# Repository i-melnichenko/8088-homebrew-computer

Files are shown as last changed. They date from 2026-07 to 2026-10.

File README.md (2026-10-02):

# 8088 Homebrew Computer

An open-source modular computer built around the Intel 8088 CPU.

## Overview

This project explores the design of a modular 8088-based computer using
through-hole DIP components and a custom expansion architecture.

The project is developed incrementally, starting with a minimal working
system and gradually adding new hardware and software capabilities.

## Firmware and host tools

The [ROM BIOS](firmware/8088-mainboard/README.md) builds a 32 KiB EEPROM image
and runs a UART monitor directly from ROM. It initializes an
HD44780-compatible 20×4 LCD on `Exp1` and a GM16C550 UART on `Exp0`, then
loads and runs programs in SRAM. The boot menu can test payload RAM, show board
information and run UART-loaded programs. Default OS boot is not implemented
yet.

Build the BIOS with NASM, then use [boardctl](tools/boardctl/README.md) on the
host to communicate over the UART. `boardctl` requires Go 1.26 or later and
uses macOS `stty` to configure the serial port. From the repository root:

```sh
make -C firmware/8088-mainboard
go -C tools/boardctl run ./cmd -port /dev/cu.usbserial-XXXX info
go -C tools/boardctl run ./cmd -port /dev/cu.usbserial-XXXX keyboard
```

The menu remains on the board LCD; `keyboard` sends Up/Down, Enter and Esc
from the host terminal. Programs receive the same input through polled INT 16h;
revision 1 does not use hardware interrupts. `boardctl` also supports program
upload and management, RAM inspection, and EEPROM readback. EEPROM writing is
not implemented on revision 1. See the [firmware guide](firmware/8088-mainboard/README.md)
for builds and BIOS behavior, and the [boardctl guide](tools/boardctl/README.md)
for commands and examples.

## Mainboard Rev. 1.0

| Front | Back |
| --- | --- |
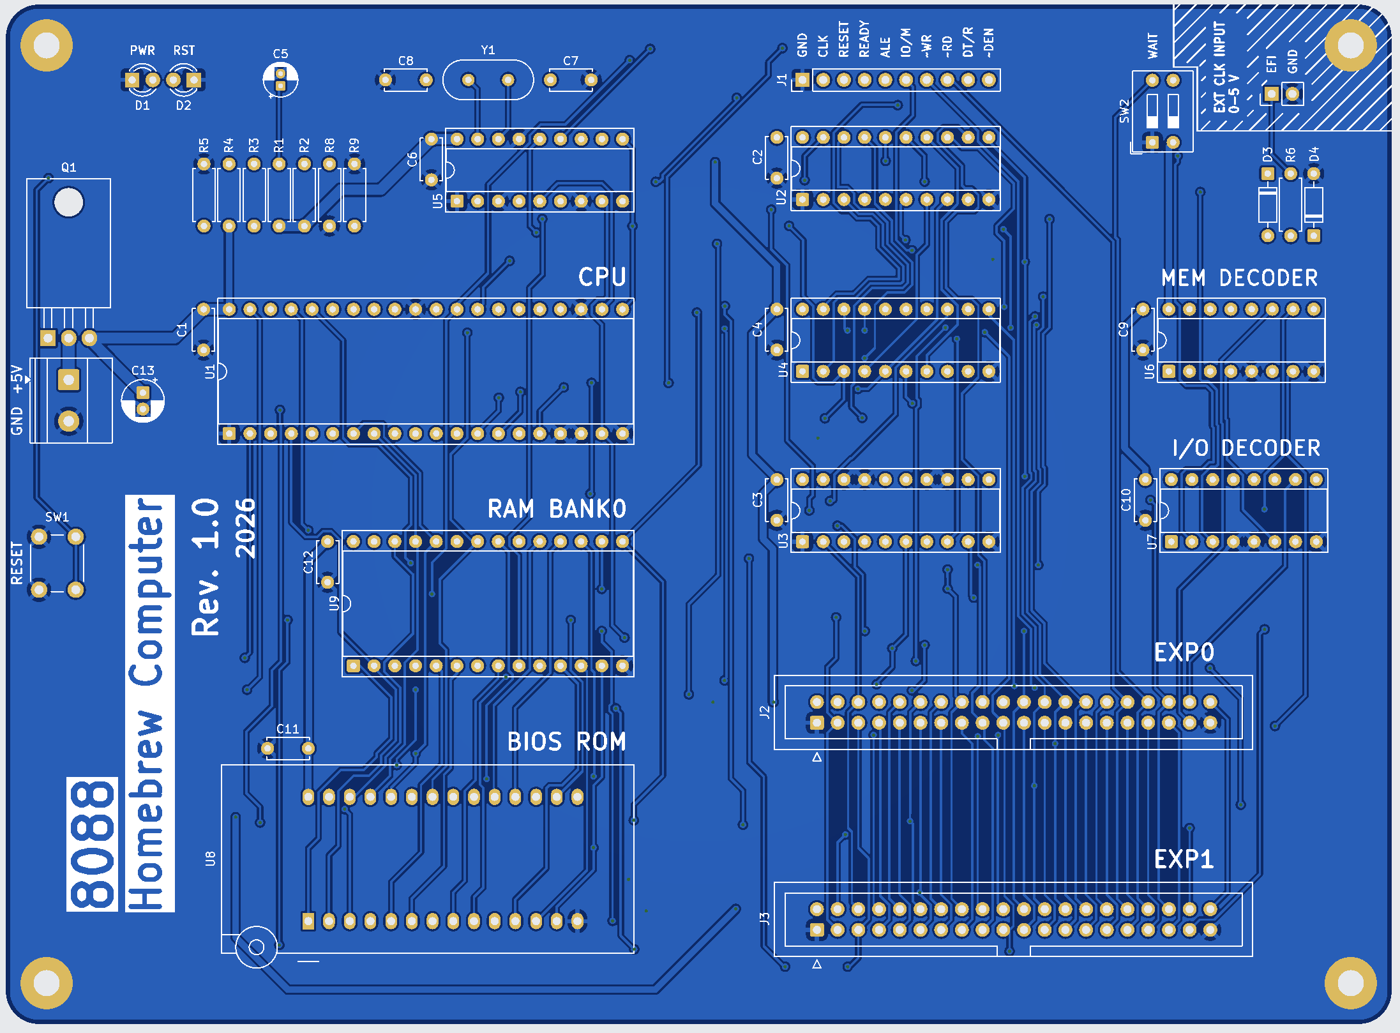
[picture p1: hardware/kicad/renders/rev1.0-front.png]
Front render
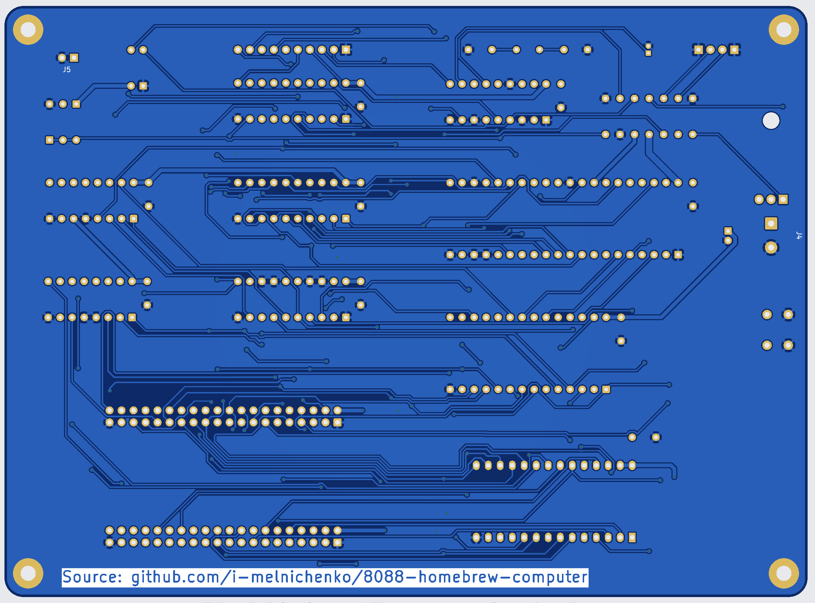
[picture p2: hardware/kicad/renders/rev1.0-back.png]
Back render
|  |  |

### Bill of materials

The table below is derived from [`hardware/kicad`](hardware/kicad). All
components are through-hole.

| Designators | Qty. | Part / value | Footprint / notes |
| --- | ---: | --- | --- |
| U1 | 1 | Intel 8088, minimum mode | DIP-40, 15.24 mm socket footprint |
| U2, U3 | 2 | 74LS373 | DIP-20, 7.62 mm socket footprint |
| U4 | 1 | 74LS245 | DIP-20, 7.62 mm socket footprint |
| U5 | 1 | 8284 clock generator / driver | DIP-18, 7.62 mm socket footprint |
| U6, U7 | 2 | 74LS138 | DIP-16, 7.62 mm socket footprint |
| U8 | 1 | 28C256 EEPROM | DIP-28 socket footprint; 3M 228-1277-00-0602J |
| U9 | 1 | HM62256BLP SRAM | DIP-28, 15.24 mm socket footprint |
| Q1 | 1 | NDP6020P P-channel MOSFET | TO-220-3, horizontal tab-down |
| Y1 | 1 | 14.31818 MHz crystal | HC-49/U, vertical |
| R1, R2, R5, R8, R9 | 5 | 10 kΩ | DIN0207 axial, 7.62 mm pitch |
| R3 | 1 | 680 Ω | DIN0207 axial, 7.62 mm pitch |
| R4 | 1 | 2 kΩ | DIN0207 axial, 7.62 mm pitch |
| R6 | 1 | 1 kΩ | DIN0207 axial, 7.62 mm pitch |
| C1–C4, C6, C9–C12 | 9 | 100 nF ceramic | Disc capacitor, 5.00 mm pitch |
| C5 | 1 | 10 µF electrolytic | Radial, 1.50 mm pitch |
| C13 | 1 | 220 µF electrolytic | Radial, 2.00 mm pitch |
| D1 | 1 | Power LED | 3 mm THT LED |
| D2 | 1 | Reset LED | 3 mm THT LED |
| D3, D4 | 2 | BAT85 Schottky diode | DO-35 / SOD-27, 7.62 mm pitch |
| SW1 | 1 | Reset pushbutton | 6 mm THT tactile switch |
| SW2 | 1 | 2-position DIP switch | SPST ×2, 2.54 mm pitch |
| J1 | 1 | 10-pin connector | 1×10 pin header, 2.54 mm pitch |
| J2, J3 | 2 | Expansion connectors (Exp0, Exp1) | IDC header, 2×20, 2.54 mm pitch |
| J4 | 1 | 5 V power input | 2-pin Phoenix MKDS-1,5, 5.08 mm pitch |
| J5 | 1 | External clock input | 1×2 pin header, 2.54 mm pitch |

> **Rev. 1.0 note:** Do not populate C7 or C8. These capacitors were removed
> from the Rev. 1.1 design.

For ICs, sockets are recommended; the PCB footprints already provide for them.

### Display module

The table below is derived from the
[`display-module` schematic](hardware/kicad/display-module/display-module.kicad_sch).

| Designators | Qty. | Part / value | Footprint / notes |
| --- | ---: |---| --- |
| U1 | 1 | 74LS00 | DIP-14, 7.62 mm socket footprint |
| U2 | 1 | 74LS373 | DIP-20, 7.62 mm socket footprint |
| DS1 | 1 | WC1602A 16×2 LCD in schematic; current build uses a 20×4 LCD | 1×16, 2.54 mm pin socket |
| C2, C3 | 2 | 100 nF ceramic | Disc capacitor, 5.00 mm pitch |
| R2 | 1 | 650 Ω | DIN0207 axial, 7.62 mm pitch |
| RV1 | 1 | 10 kΩ potentiometer | Runtron RM-065, vertical |
| J1 | 1 | Expansion connector (Exp1) | 2×20 pin socket, 2.54 mm pitch |

### UART module

The table below is derived from the
[`uart-module` schematic](hardware/kicad/uart-module/uart-module.kicad_sch).

| Designators | Qty. | Part / value | Footprint / notes |
| --- | ---: | --- |---|
| U1 | 1 | GM16C550 UART | DIP-40, 15.24 mm |
| Y1 | 1 | 1.8432 MHz crystal | HC-49/U, vertical |
| C1 | 1 | 22 pF ceramic | Disc capacitor, 5.00 mm pitch  |
| C2 | 1 | 47 pF ceramic | Disc capacitor, 5.00 mm pitch  |
| C3 | 1 | 100 nF ceramic | Disc capacitor, 5.00 mm pitch  |
| R3–R6 | 4 | 10 kΩ | DIN0207 axial, 7.62 mm pitch |
| R1 | 1 | 1 MΩ | DIN0207 axial, 7.62 mm pitch |
| R2 | 1 | 1.5 kΩ | DIN0207 axial, 7.62 mm pitch |
| R7 | 1 | 1 kΩ | DIN0207 axial, 7.62 mm pitch |
| R8 | 1 | 2 kΩ | DIN0207 axial, 7.62 mm pitch |
| J1 | 1 | Expansion connector (Exp0) | 2×20 pin socket, 2.54 mm pitch |
| J2 | 1 | CP2102 module | 1×03 pin header, 2.54 mm pitch |

## Links

- [DIY EEPROM Programmer](https://github.com/erikvanzijst/eeprom)

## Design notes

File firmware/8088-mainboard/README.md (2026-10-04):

# 8088 mainboard firmware

There is one active ROM BIOS. It initializes both available console devices:
the 20×4 HD44780-compatible LCD on Exp1 and the GM16C550 UART module on Exp0.
The monitor runs directly from ROM at `F800:0000`; uploaded programs execute
from paragraph-aligned SRAM addresses allocated by BIOS.

BIOS sources are grouped by responsibility:

- `bios/uart/`: wire protocol constants, framing, command dispatch and handlers
  for programs, memory, keyboard events, Info and flasher mode.
- `bios/`: initialization, the cooperative monitor loop, shared SRAM state,
  keyboard queue, program allocation, LCD menu and interrupt API.
- `bios/utils/`: self-contained BIOS utilities such as the RAM diagnostic.
- `lib/`: shared hardware drivers and the program BIOS API definitions.
- `programs/flasher/`: the standalone RAM flasher, sharing UART framing and
  protocol constants with BIOS.

## Build

Run these commands from `firmware/8088-mainboard`. NASM is required for
local builds; Go is required for the UART tools.

```sh
make        # build/bios.bin, a complete 32 KiB 28C256 image
make citylights # build/citylights.bin, UART-loaded city animation
make terminal  # build/terminal.bin, UART-to-LCD terminal
make clean
```

BIOS builds print occupied ROM bytes, percentage and free space. The report
includes code/data and the reset vector, excluding `0xFF` padding.

The build supplies the BIOS version: `dev` by default, or an explicit short
identifier for CI/release builds:

```sh
make BIOS_VERSION=v1.0.0
```

Use 1–9 ASCII characters (letters, digits, dots, hyphens or underscores) so
the version remains readable in the LCD header and Info list. The same version
appears in the menu, LCD Info and UART `INFO` reply. BIOS is rebuilt on each
invocation to apply version changes without `make clean`; example programs
still build incrementally. Board revision, UART protocol version and BIOS API
revision are independent. `make test BIOS_VERSION=ci-test` also passes the
version to the Docker build.

## UART and menu control

```sh
make serial-ports
make keyboard SERIAL_PORT=/dev/cu.usbserial-XXXX
make serial SERIAL_PORT=/dev/cu.usbserial-XXXX
```

`make serial` opens the UART console through `boardctl`, without `cu` lock
files or `sudo`; use `Ctrl-C` to leave it. The UART uses `A0h` through `A7h` and is configured for 9600 8N1 from the
module's 1.8432 MHz crystal. The LCD remains on `C0h` (commands) and `C1h`
(data). See the [boardctl guide](../../tools/boardctl/README.md) for CLI commands.

### Boot menu

After boot, the ROM BIOS shows a menu: **Default boot**, **Custom programs**,
**Memory check**, and **Info**. Default boot currently reports `NO BOOT TARGET`;
there is no countdown or DOS loader yet. All menu/monitor code executes from
EEPROM, not copied to RAM. RAM holds only buffers, state, stack and explicit
user uploads; the diagnostic writes RAM only after confirmation.

The first LCD row is the current section header, except for the two-line
Memory check warning dialog. Progress, success, failure and cancellation retain the `MEMORY CHECK`
header; changing status uses rows 2–4. `INFO` is a scrollable list with three
visible rows: BIOS version, board revision, CPU, physical RAM/ROM sizes, LCD,
UART, protocol/API revisions, committed program count and address ranges.
Up/Down scroll one row without wrapping, Enter does nothing, Esc returns to
the selected root item. The rightmost column shows the same `^`/`v` rail as
the menu, without a selection cursor. Reopening Info starts at the top.
The UART `INFO` command still returns its compact ASCII summary.
While launching a payload,
the program name stays on row 1 and `RUNNING PROGRAM` appears on row 2.
The payload then owns the LCD and may use its own layout.

`boardctl keyboard` shares the PC terminal keyboard; the menu is shown only
on the board LCD. Use Up/Down, Enter and Esc to navigate. Ordinary letters,
including `U` and `Q`, belong to the program, not the host utility.
Press `Ctrl-]`, then `u` for a binary path prompt; `Ctrl-C` disconnects directly
and restores the PC terminal, including from the prompt.
Uploads are available only while the ROM menu is active; the new slot is
selected without starting it. Enter opens its details; Enter again starts it.
The submenu always contains four slots, initially Empty.
The last LCD column shows `|` with `^`/`v` for hidden items above/below.
The selected `>` blinks in the root and Custom programs menus, and becomes
visible again on navigation. Only that LCD cell is updated; UART polling
continues without a blocking delay. Revision 1 counts idle-loop iterations,
so the blink rate depends on CPU speed and monitor traffic, not a hardware
timer. Info and other non-selectable pages do not blink.
Use one serial client at a time; do not run a
separate `upload` process while `keyboard` owns the port. Ordinary `upload`
works from any menu page except during an active RAM test.

Revision 1 has no hardware interrupts. The ROM loop polls keyboard packets;
RAM programs must call INT 16h/AH=01h regularly, or wait with AH=00h, to poll
the transport. AH=01h does not consume a key. A program that does not poll
cannot accept keyboard packets; host timeouts and UART overflow are possible.
The BDA holds a 15-key queue shared by the menu and INT 16h. Keyboard sharing
owns UART RX: raw INT 14h/AH=02h is rejected until the host detaches.
`console` remains a separate raw UART mode. Attach keyboard sharing from the
ROM menu before launching a program. Reset disables sharing; reconnect the
host session afterward. If detach cannot be acknowledged, Reset restores raw mode.

## Uploaded programs

For example, build the city animation with `make citylights`, then upload
and start it from this directory:

```sh
go -C ../../tools/boardctl run ./cmd -port /dev/cu.usbserial-XXXX upload \
  --name "City Lights" --run ../../firmware/8088-mainboard/build/citylights.bin
```

Omit `--run` to add the program to the menu without starting it. The animation
shows `CITY LIGHTS` over the skyline for about two seconds, then alternates
between night and day. Stars twinkle between a bright shape and a dim dot at
night; clouds drift left during the day. One pedestrian paces on the left,
while two small buildings remain on the right.
The moon and sun stay in place. Each scene lasts about five seconds before a
right-to-left column wipe reveals the next one. The lower-right `ESC:BACK`
hint appears for about three seconds, hides for
about ten, and repeats; Esc always returns to BIOS. Timing is approximate on
rev1 because it has no hardware timer.

The `terminal` example displays keyboard input on the LCD and echoes it over
UART. Its header and controls stay on the top two rows; Esc returns to BIOS.

The host sends a name, image size and CRC; BIOS assigns an ID and a
paragraph-aligned address. Up to four programs
may coexist. First-fit allocation reuses deleted ranges without relocating
resident programs; allocations remain paragraph-aligned. `PROGRAM_DELETE`
frees a slot/range and shifts following IDs; `PROGRAM_RENAME` changes only its
name. Both operations refresh the LCD and require no active upload/test/program.
The current upload area is `0x8800..0xFBFF` (29,696 bytes total, less alignment gaps).
The first 2 KiB of physical SRAM are reserved for IVT, BDA and BIOS state;
`0xFC00..0xFFFF` is reserved for program and BIOS stacks. The decoder mirrors
the 32-KiB SRAM every 32 KiB within `0x00000..0x1FFFF`.
BIOS maintains the sequential upload cursor; DATA packets contain only program
bytes, 128 per block except the final remainder. Uploads must be
fully received with matching image CRC before a slot becomes runnable. Retried PROGRAM_UPLOAD_DATA packets
are acknowledged without counting their data twice. The LCD shows transfer
progress as a 20-character `[###    ]`-style bar with 18 cells between the
brackets. See [protocol v1](../../docs/uart-protocol-v1.md) for the wire format and
commands. Protocol version remains 1 during development; update BIOS and
boardctl together.

`MEMORY_READ` lets boardctl dump RAM (including BIOS state and mirrors)
in blocks of up to 127 bytes. It is available in the ROM menu, not during a
memory check or program execution. ROM, unmapped and out-of-range reads are rejected;
live BIOS state is not an atomic snapshot. See the boardctl
[dump examples](../../tools/boardctl/README.md#commands).

`MEMORY_WRITE` permits raw writes only to payload SRAM and its aliases, never
ROM, IVT/BDA, BIOS state or stacks. Writes are rejected while an upload, memory
check or program is active. It does not register programs; boardctl `write`
verifies written bytes by SHA-256 readback.

Normal RETF preserves uploaded programs; Reset, power-off or jumping to
`F800:0000` clears the registry. There is no memory isolation between programs
and BIOS.

## BIOS flasher mode

`BIOS_FLASHER_MODE()` copies the built-in EEPROM monitor to RAM and
transfers control to it. The command has no payload; the full EEPROM
image size is fixed at 32 KiB. Entry works on revision 1 and clears the
resident program registry and keyboard sharing because the monitor occupies
payload RAM. Entry during a program upload, memory test or running program
is rejected. The RAM monitor's ACK confirms it is ready.

Only `BIOS_WRITE`, `BIOS_READ`, `RESET` and `PING` work in this mode; other
requests return status 20. An identical entry retry repeats its ACK. On
revision 1, a valid WRITE returns status 17 (unsupported), READ reads EEPROM in blocks
of 1–127 bytes, and RESET returns to the unchanged ROM BIOS. In the ordinary
ROM menu, READ and WRITE return status 17; enter EEPROM mode to read.
Both commands carry physical addresses and validate the entire block within
`0xF8000..0xFFFFF` in the RAM flasher; invalid requests return status 18.
The UART configuration/FIFO are preserved during
entry; hardware interrupts stay disabled and all monitor code runs from RAM.

The LCD switches to a `BIOS FLASHER` status screen in the same four-row style
as BIOS: section header, operation result, EEPROM address range and
`HOST RESET TO EXIT`. Entry shows `READY - READ ONLY`; successful reads show
`READ OK` and the inclusive physical range of the block. Revision-1 writes
show `WRITE UNSUPPORTED`, while invalid requests display an error. PING and
identical entry retries preserve the latest operation result. LCD updates
run one short operation per UART polling iteration, entirely from RAM.
RESET returns to the BIOS menu; keyboard navigation is disabled in this mode.

The revision-2 contract uses the same mode and commands, adding EEPROM writes
in WRITE; the write driver is not implemented yet. Blocks are written and
verified immediately. The host can read the
complete image with READ and compare SHA-256 before RESET; after a write,
RESET requires all 32 KiB to have been written and verified by readback.
See the [wire contract](../../docs/uart-protocol-v1.md#bios-flasher-mode).
The flasher lives in [`programs/flasher/main.asm`](programs/flasher/main.asm);
EEPROM hardware drivers belong in `lib/`. The flasher is assembled separately
with `ORG 0` so it can execute from RAM without calling ROM services.
`make bios` builds the normal 32-KiB EEPROM image containing the RAM monitor;
it does not build a second BIOS image. boardctl exposes `bios-flasher-mode`, `bios-read`
and `bios-write`; see its [EEPROM guide](../../tools/boardctl/README.md#bios-flasher-mode).

## Memory check

Memory check asks for confirmation because it destroys all uploaded programs.
The dialog shows `ALL RAM PROGRAMS` and `WILL BE DELETED!` on rows 1–2,
a blank row 3 and `YES:ENTER  NO:ESC` on row 4. Enter starts the destructive
test; Esc returns to the menu without changing programs or their RAM contents.
It tests the complete 32-KiB SRAM through its `0x8000..0xFFFF` alias. The
program area (`0x8800..0xFBFF`) uses destructive write/read passes; the IVT,
BDA, monitor/API state and stacks are checked one byte at a time and restored
after each probe. The five test values are `00`, `FF`, `55`, `AA`, and
address-dependent data. Row 2 shows overall progress across
all ten passes with the same bracketed 18-cell bar; row 3 shows the current
inclusive 16-byte RAM range,
and row 4 shows six-digit decimal `OK`/`BAD` counters. These count byte
verifications, not unique addresses: each of 32,768 bytes is checked five
times, so a successful full test reports `OK:163840 BAD:000000`. Writes do
not increment these counters. Testing continues after mismatches and retains
the first failing address, expected and actual byte in BIOS state. After
completion row 3 shows `DONE FFF0-FFFF`, or `FAIL xxxx-yyyy` for the block
containing the first mismatch. After cancellation it shows `STOP xxxx-yyyy`
for the last processed block. Completion keeps a full bar and the
totals, while cancellation keeps partial progress and counters.
Esc cancels. Cancellation also invalidates
all old programs. This is a basic diagnostic, not an exhaustive
RAM certification test. UART requests remain serviceable throughout the test.

## Program BIOS API

Programs call real software interrupts: INT 10h for text/cursor/scrolling,
INT 14h for UART, INT 16h for UART-backed keyboard, and INT 60h for board
LCD services, including custom CGRAM glyphs. Include `lib/bios_api.inc`;
the examples no longer include their own copies of the hardware drivers.
Programs use `ORG 0`, start with `DS=CS`, preserve `SS/SP`, and use `RETF`
to return to the menu. Handlers live in ROM and return with IRET, preserving caller segments,
stack and non-output registers/flags. Revision 1 needs no PIC for software INT.
See [bios-api.md](docs/bios-api.md) for exact registers, flags, supported
functions, memory aliases and limitations. This is not a full PC/MS-DOS BIOS.

## Software verification

The Docker tests execute the actual ROM image with Unicorn and emulated
UART/LCD. They cover keyboard navigation, LCD output, upload retries and bounds,
RAM pass/fail/cancel, program return, SRAM mirrors and INT API contracts.
The emulator implements CPU IVT dispatch; real ROM handlers and IRET execute.
It does not verify hardware timing.

Run the emulator checks in Docker (Docker must be running):

```sh
make test
```

The image installs NASM/Make and the pinned Unicorn dependency, rebuilds the
ROM inside Linux, then runs the tests. It does not access the EEPROM, serial
devices, or write host build files. This is a test runner, not an interactive
virtual board. `EMULATOR_IMAGE` overrides the local Docker image name.

## Current scope

There is no automatic boot countdown, bootable storage or MS-DOS loader yet.
Revision 1 polls UART and does not use hardware interrupts. The implemented
software INT services are a starting point, not a complete PC-compatible BIOS.
Revision 2 can extend these services, add hardware interrupt support, memory
discovery and storage boot while keeping one BIOS implementation.

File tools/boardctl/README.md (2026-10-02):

# boardctl

`boardctl` is the host-side command-line tool for the 8088 mainboard monitor
protocol. It communicates over the GM16C550 UART at 9600 8N1 and loads flat
16-bit binaries into SRAM.

The wire format is documented in [uart-protocol-v1.md](../../docs/uart-protocol-v1.md).

## Build

Go 1.26 or later is required.

```sh
go build -o boardctl ./cmd
```

The tool uses the macOS built-in `stty` command to configure the serial device.

## Monitor status

The monitor executes directly from ROM at `F800:0000`. It implements `keyboard`, `info`,
`upload`, `programs`, `run`, `delete`, `rename`, `dump`, `write`, `ping`, and `reset`;
uploaded programs execute from SRAM.
`bios-flasher-mode`, `bios-read` and `bios-write` use the built-in RAM flasher.

The `console` command is usable now. The default device is
`/dev/cu.usbserial-110`; use `-port` to select another one.

```sh
./boardctl -port /dev/cu.usbserial-XXXX info
```

## Commands

```sh
# Open a plain UART console. Ctrl-C exits.
./boardctl -port /dev/cu.usbserial-XXXX console

# Share the PC keyboard; menu and program output stay on the board LCD.
./boardctl -port /dev/cu.usbserial-XXXX keyboard

# Print BIOS/board revision, memory map and UART settings.
./boardctl -port /dev/cu.usbserial-XXXX info

# Check the connection in either the ROM menu or RAM flasher.
./boardctl -port /dev/cu.usbserial-XXXX ping

# Name a program, let BIOS allocate RAM, and immediately execute it.
./boardctl -port /dev/cu.usbserial-XXXX upload \
  --name "City Lights" --run ../../firmware/8088-mainboard/build/citylights.bin

# List resident program IDs, names, addresses and sizes.
./boardctl -port /dev/cu.usbserial-XXXX programs

# Execute a binary that was previously uploaded.
./boardctl -port /dev/cu.usbserial-XXXX run 1

# Rename a resident without reloading it, or delete it and free its RAM.
./boardctl -port /dev/cu.usbserial-XXXX rename 1 Penguins
./boardctl -port /dev/cu.usbserial-XXXX delete 1

# Return execution to ROM reset handling.
./boardctl -port /dev/cu.usbserial-XXXX reset

# Print 256 bytes of RAM as an address/hex/ASCII dump.
./boardctl -port /dev/cu.usbserial-XXXX dump --addr 0x8800 --size 256

# Save the 32-KiB RAM bank to a new binary file.
./boardctl -port /dev/cu.usbserial-XXXX dump \
  --addr 0 --size 32768 --output ram-dump.bin

# Write raw bytes into payload RAM, then verify SHA-256 by readback.
./boardctl -port /dev/cu.usbserial-XXXX write --addr 0x9000 patch.bin

# Enter the RAM flasher and save the complete EEPROM image (works on Rev.1).
./boardctl -port /dev/cu.usbserial-XXXX bios-read --output bios-dump.bin

# Read EEPROM and compare its SHA-256 with a local 32-KiB BIOS image.
./boardctl -port /dev/cu.usbserial-XXXX bios-read \
  --verify ../../firmware/8088-mainboard/build/bios.bin

# Flash on writing hardware, verify SHA-256, then reset to the new BIOS.
./boardctl -port /dev/cu.usbserial-XXXX bios-write --reset \
  ../../firmware/8088-mainboard/build/bios.bin
```

`upload` sends name, size and image CRC in `PROGRAM_UPLOAD_BEGIN`, receives an ID and
address, sends `PROGRAM_UPLOAD_DATA` payloads containing only program bytes
(128 per block, except the final remainder). Before `PROGRAM_UPLOAD_COMMIT`,
boardctl reads the entire assigned range back through `MEMORY_READ` and compares
its SHA-256 with the original binary on the PC. Only a matching hash permits
COMMIT with the one-byte program ID. Read failures or mismatched hashes trigger
ABORT where possible; the program is not committed or run. Hash mismatches
report both PC and RAM hashes. This check also applies to uploads from keyboard
sharing. Readback adds roughly another transfer's worth of UART time.
BIOS still independently verifies the image CRC16 during COMMIT.
BIOS advances its own write cursor; boardctl
waits for each ACK and retries the same sequence on timeout.
The LCD displays `RECEIVING...` and a 20-cell progress bar during the
transfer. The current SRAM upload range is `0x8800` through `0xFBFF`
(29,696 bytes); the upper 1 KiB is reserved for the stack.
Up to four named programs may coexist. BIOS assigns paragraph-aligned addresses
starting at `0x8800`; `--addr` is no longer supported. Programs use `ORG 0`,
DS=CS, preserve SS/SP and return with RETF. Old ORG-0200 binaries must be rebuilt.
The INT API reserves IVT/BDA and state below 8800h; update boardctl and BIOS
together. Programs may use the [BIOS API](../../firmware/8088-mainboard/docs/bios-api.md) rather than
including hardware drivers. Both examples have been migrated.
Name defaults to the file stem; `--name` overrides it. Names must be unique,
1–15 printable ASCII characters and not all spaces. Failed uploads are aborted
where possible; already committed programs remain available.

`rename ID NAME` preserves the program's address, size and bytes; the new name
follows the same 1–15 ASCII and uniqueness rules as upload. `delete ID` frees
the slot and allocation but does not erase RAM or relocate other programs.
BIOS uses first-fit allocation to reuse deleted ranges. Following program IDs
shift after deletion: run `programs` again before using saved IDs. Both commands
require the ROM menu and no pending upload or memory check. Deleting switches
the LCD to Custom programs. Retries cannot delete the next ID a second time.

`dump` uses `MEMORY_READ` in chunks of at most 127 bytes. Both `--addr` and
`--size` are required; decimal and `0x`-prefixed hex are supported. The range
must lie entirely in RAM `0x00000..0x1FFFF` (four mirrors of 32 KiB).
ROM reads are rejected. Protected BIOS RAM is readable, but live state and buffers
are not atomic snapshots. Use the ROM menu: memory checks reject reads, and
running programs cannot be dumped. With `--output`, the file is created only
after a successful full read; existing files are never overwritten.

`write --addr ADDRESS FILE` uses `MEMORY_WRITE` in chunks of at most 124 bytes.
Both boardctl and BIOS check the entire range: only payload RAM `0x8800..0xFBFF`
and its aliases (`0x00800..0x07BFF`, `0x10800..0x17BFF`, `0x18800..0x1FBFF`) are
writable. ROM, unmapped memory, IVT/BDA, BIOS state and stacks are protected.
After writing, boardctl reads the entire range back and checks SHA-256. Writes
are rejected during uploads, memory checks and program execution. Raw writes
do not create a menu slot: use `upload` for programs. Existing program bytes
can be overwritten, and a failed multi-block write may leave a partial patch;
there is no rollback.

## BIOS flasher mode

`bios-flasher-mode` sends `BIOS_FLASHER_MODE` with an empty payload. Entry copies
the BIOS's embedded flasher to RAM and clears resident programs and keyboard
sharing. The EEPROM
image is always 32,768 bytes. This command works on Rev.1. In EEPROM mode only
`BIOS_WRITE`, `BIOS_READ`, `PING` and `RESET` are available, plus an identical
lost-ACK entry retry. Use `ping` to check the connection and `reset` to return
to the ROM BIOS when firmware permits it.

`bios-read [--output FILE] [--verify FILE]` reads all 32 KiB using `BIOS_READ`
blocks of up to 127 bytes and prints the EEPROM SHA-256. Requests carry physical
addresses in `0xF8000..0xFFFFF`; the host and flasher validate the entire range.
RAM, EEPROM mirrors and addresses outside this window are rejected. It probes the mode:
from the ROM menu it enters the RAM flasher automatically;
if already in the flasher it reads without reentering. `--verify` compares
SHA-256 with an exact 32-KiB file, including padding
and reset vector. `--output` saves a new binary file only after all reads and
any requested verification succeed; existing files are never overwritten.
The command leaves the board in EEPROM mode and does not reset it.

`bios-write [--reset] [--timeout DURATION] FILE` requires an exact 32-KiB image
and a board in its ordinary ROM menu. It probes the mode before entering the RAM
flasher, then sends consecutive 64-byte EEPROM pages through
`BIOS_WRITE`. Each request is acknowledged before the next page; retries keep
the same sequence, physical address and bytes, including across sequence wrap. The RAM
flasher performs per-block write/readback checks. boardctl then reads
the entire EEPROM through `BIOS_READ` and compares SHA-256 with the source.
`--reset` sends RESET only after that verification succeeds; otherwise the
board remains in the RAM flasher. Any write/readback error stops the transfer
without sending RESET. The per-WRITE-attempt timeout defaults to 10 seconds
and can be increased, for example `--timeout 30s`, for EEPROM programming and
readback verification.

Rev.1 supports entry and readback; a valid WRITE returns status 17
(`unsupported operation`) without writing. Invalid requests in the RAM flasher
return status 18. The Rev.2 EEPROM write driver is not implemented in the
current firmware; the host flash command implements its
protocol contract. An already active EEPROM session is rejected for a new
flash. After a SHA-256 mismatch, do not reset into the unverified BIOS.
The protocol permits a new full transfer from the active flasher after
completion, starting with WRITE at `0xF8000`; the current CLI does not expose
that recovery operation. The host does not reset or restart a write automatically.

## Keyboard sharing

Run from this directory without building a binary:

```sh
go run ./cmd -port /dev/cu.usbserial-0001 keyboard
```

The entry point is `cmd/main.go`; application logic lives in `internal/apps`.
`internal/client` handles monitor requests, response matching, and retries;
`internal/protocol` encodes and decodes wire frames.
`keyboard` translates terminal input into ASCII/PC-style scan-code events.
It does not fetch, redraw or mirror the BIOS menu on the PC.
It restores the terminal settings on normal exit and handled signals.

Connect while the board is in its ROM menu, then use Up/Down, Enter and Esc
to navigate on the LCD. Wait for `Keyboard connected` before typing: while
attaching, the terminal is still in its normal mode. Ctrl-C cancels attachment
as well as an active session, including while a key acknowledgement is pending.
Failed/interrupted attachment also attempts to detach, since BIOS may have
accepted the request before its acknowledgement was received. A malformed
keyboard acknowledgement reports its actual payload bytes and length.
Programs read the same input through INT 16h.
UART reads are nonblocking and return periodically even without incoming
bytes; write waits are bounded. This lets retry deadlines and Ctrl-C run on
macOS instead of getting stuck inside Go's file readiness wait. The serial
descriptor stays open while `stty` configures it, so closing the configuration
command does not reset settings before the UART exchange.
Letters, including `U` and `Q`, and Ctrl-Z are forwarded to the program.
Arrows, Home/End, Insert/Delete, Page Up/Down and F1..F10 are translated;
modifier state, key releases and Unicode text are not supported.

Press `Ctrl-]`, then `u` to open a path prompt. Paste/type a binary path, press Enter to upload to
an address assigned by BIOS. Its file stem becomes the program name. After
upload the new Custom programs slot is selected: Enter opens details, then
Enter runs it. Paths may contain
spaces; shell quote characters and `~` are not expanded. Esc cancels the prompt.
Uploads are allowed only after returning to the BIOS menu. `Ctrl-C` detaches
and quits directly, including from the upload prompt. It is intercepted in
raw mode and not forwarded to BIOS. Terminal
settings are restored on exit. `Ctrl-]`, then `q` remains an exit alias;
`Ctrl-]`, then `]` forwards a literal Ctrl-].

Revision 1 has **no hardware interrupts**. In RAM programs, INT 16h/AH=00h
waits while polling input; AH=01h polls and peeks without consuming a key.
Programs doing other work must call AH=01h regularly. A program that does not
poll cannot acknowledge keyboard events; long delays can overflow the UART
FIFO. The BIOS ring holds up to 15 keys after packets have been received.
The host reports failed acknowledgements/queue errors; it does not promise
unlimited buffering or asynchronous input. Raw INT 14h receive is unavailable
while sharing owns RX. UART TX/status still work, but this mode does not
display program UART output. Use `console` separately for raw UART programs.

Sharing survives ordinary RETF. Reset disables sharing, so restart the host
session after Reset. If a non-polling program prevents detach, Reset restores
raw UART mode. Do not attach sharing to an already-running raw-input program.

Only one process may own the serial port. Use the built-in upload action while
sharing, or close the session before using the separate `upload` command.
Custom programs has four slots, initially Empty. The rightmost LCD column
shows `^`/`v` when more items exist above/below. Reset and confirmed memory
check clear the registry; ordinary program return preserves it.
Menu memory check erases the payload only after confirmation; an active test
rejects uploads and can be cancelled with Esc. Info is a scrollable LCD list:
Up/Down scroll, Esc returns, Enter has no action. The host `info` command
continues to print a compact summary rather than the LCD list. Default boot is a placeholder;
there is no automatic countdown, persistent program selection, or DOS boot yet.

## Current scope

Protocol v1 implements `PING`, `INFO`, `RESET`, `BIOS_FLASHER_MODE`, `BIOS_WRITE`,
`BIOS_READ`, `MEMORY_READ`, `MEMORY_WRITE`; `PROGRAM_UPLOAD_BEGIN`, `PROGRAM_UPLOAD_DATA`,
`PROGRAM_UPLOAD_COMMIT`, `PROGRAM_UPLOAD_ABORT`; `PROGRAM_LIST`, `PROGRAM_EXEC`,
`PROGRAM_DELETE`, `PROGRAM_RENAME`; and
`KEYBOARD_MODE`, `KEYBOARD_EVENT`. Version stays 1 during development; update BIOS and boardctl
together. Each packet uses COBS framing, CRC-16/CCITT-FALSE, sequence numbers,
and host retries. Firmware status 17–20 is reported with a description.
Execution debugging is not implemented.

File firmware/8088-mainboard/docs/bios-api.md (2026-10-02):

# ROM BIOS software-interrupt API

API revision **1** runs on the revision-1 8088 board using real software
interrupts. It is independent of the UART wire protocol version (also 1).
This is a documented subset of PC-style BIOS services plus board extensions,
not a complete IBM PC BIOS or a claim that stock MS-DOS can boot.

## Memory and execution

The current decoder selects RAM for physical 00000h..1FFFFh. Its 32-KiB
SRAM uses A0..A14 only: addresses separated by 8000h refer to the same bytes.
They are aliases, not additional memory. BIOS keeps its existing upper-alias
execution convention, reserving the corresponding low-memory structures:

| Canonical SRAM bytes | Upper alias | Purpose |
| --- | --- | --- |
| 0000..03FF | 8000..83FF | 256 interrupt vectors, offset:segment |
| 0400..04FF | 8400..84FF | BIOS Data Area, partial implementation |
| 0500..06FF | 8500..86FF | monitor buffers, screen, registry |
| 0700..07FF | 8700..87FF | API LCD framebuffer, cursor, keyboard and EEPROM mode parameters |
| 0800..7BFF | 8800..FBFF | program allocations, 29,696 bytes minus alignment gaps |
| 7C00..7DFF | FC00..FDFF | program stack |
| 7E00..7FFF | FE00..FFFF | BIOS stack |

The vectors for 10h, 14h, 16h and 60h point into ROM F800:xxxx. Other vectors
currently lead to the unsupported-service handler. This is not exception
recovery: keep hardware interrupts disabled on revision 1. Software INT
works with IF=0 and does not require a PIC.

Programs remain flat 8086-compatible ORG-0 images. BIOS far-calls their
allocated segment at offset 0, with DS=CS, IF=0 and DF=0. It sets SP=FDFE
before CALL; the program sees SP=FDFA because the far return address uses
four bytes. Preserve SS/SP and use RETF to return to the menu.

Each INT uses the caller's stack and returns with IRET. Unless specified
below, AX/BX/CX/DX/SI/DI/BP/DS/ES and the caller's flags are preserved.
Handlers clear DF internally, then restore the caller's DF/IF through IRET.
Invalid function numbers/parameters return CF=1 and AH=86h; this error
convention is a board extension, not a claim about unspecified PC BIOS cases.
Never access service internals or depend on handler addresses.

The BDA currently initializes COM1 base (0040:0000 = A0h), physical memory
size (0040:0013 = 32 KiB), keyboard ring head/tail (001A/001C) and buffer
(001E..003D, 16 word slots with at most 15 queued keys), display mode
(0049 = custom 7Fh), columns (004A = 20),
framebuffer byte count (004C = 80), page-0 cursor (0050), and last row
(0084 = 3). Other fields are reserved, not implemented PC services.
There is no PC video memory at B800:0000 and no attribute framebuffer.

## INT 10h — LCD text console

Only page BH=0 is supported, except AH=06h where BH is the ignored attribute.
Coordinates are zero-based, row 0..3 and column 0..19.

| AH | Inputs | Operation / outputs |
| --- | --- | --- |
| 02h | BH=0, DH=row, DL=column | Set logical cursor and LCD DDRAM position |
| 03h | BH=0 | Return DX=row:column, CX=2000h (hidden cursor) |
| 06h | AL=lines, BH=attribute, CH/CL=top/left, DH/DL=bottom/right | Scroll the inclusive rectangle upward; AL=0 or AL>=height clears it |
| 0Eh | BH=0, AL=character | Write character, advance cursor and scroll when necessary |

Attributes/colors are ignored on this monochrome character LCD. Teletype
interprets CR (column zero), LF (next row, retaining column), BS (move left,
without erasing or crossing the row boundary), and BEL (no speaker, no-op).
Writing the final column wraps; reaching past row 3 scrolls the whole screen.
Valid video calls preserve FLAGS. This 20x4 custom mode is not PC mode 3.

## INT 14h — serial port

DX is the BIOS port index, **0** for the sole UART, not the A0h I/O address.

| AH | Inputs | Outputs / operation |
| --- | --- | --- |
| 00h | DX=0, AL=E3h | Initialize 9600 8N1, reset FIFOs and keyboard queue; return status as AH=03h |
| 01h | DX=0, AL=byte | Transmit; AL retained, AH=line status or timeout |
| 02h | DX=0 | Receive; AL=byte on success, AH=line status or timeout |
| 03h | DX=0 | AH=line status, AL=modem status |

Initialization configurations other than E3h are not supported yet.
Transmit and receive poll at most 65,535 iterations. On timeout AH bit 7 is
set; do not use the receive AL then. The timeout is CPU-speed dependent,
not a millisecond clock. AH bits 0..6 come from the UART LSR; bit 7 is the
BIOS timeout indicator, not the 16550 FIFO-error-summary bit. Flags and
registers other than AX are preserved on valid calls. No UART IRQ is enabled.
While host keyboard sharing is enabled, AH=02h returns CF=1/AH=86h because
framed keyboard traffic owns UART RX. TX/status remain available; initialization
resets the FIFO and keyboard queue but does not disable sharing. UART text
output is not displayed by the host keyboard command.

## INT 16h — polled keyboard

| AH | Outputs / operation |
| --- | --- |
| 00h | Wait for a key and consume it; AL=ASCII, AH=scan code |
| 01h | ZF=1 when empty (AX unchanged); otherwise ZF=0, AX=key, without consuming |
| 02h | AL=0 modifier state; no physical keyboard modifier tracking yet |

ASCII letters, digits, basic punctuation, Esc, Tab, Backspace and CR have
PC-style scan codes. Uppercase letters use the same scan code as lowercase.
Other raw received bytes have scan code zero. In raw mode CR and LF are
distinct bytes; terminal arrow sequences are not decoded by BIOS.
Only AH=01h changes ZF; other FLAGS are retained.

`boardctl keyboard` enables framed keyboard sharing before program launch.
The host translates terminal arrows, Home/End, Insert/Delete, Page Up/Down
and F1..F10 into keys with AL=0 and a PC-style scan code in AH. Enter becomes
0D/1C, Backspace 08/0E and Esc 1B/01. No modifier/release events or PS/2
decoding are implemented. The BIOS menu consumes the same BDA queue as programs.

There are **no hardware interrupts on revision 1**. Both AH=00h and AH=01h
pump the UART frame decoder, at most one complete request per call. AH=00h
continues polling until a key is available; AH=01h is suitable for cooperative
program loops. Long work without these calls may cause UART overflow or host
timeouts. The 15-key ring cannot prevent hardware FIFO overflow before polling.
Software INT does not make input asynchronous.

For a program doing other work, poll between bounded work slices:

~~~asm
.loop:
    bios_key_peek                 ; INT 16h/AH=01h: pump UART, leave key queued
    jz .work
    bios_key_read                 ; INT 16h/AH=00h: consume, AX=scan:ASCII
    ; Handle AX here.
.work:
    ; Do a short slice of work; do not HLT waiting for a nonexistent IRQ.
    jmp .loop
~~~

In sharing mode, the program-side poll accepts keyboard mode/events and PING;
BIOS_WRITE receives status 17 (unsupported) on revision 1; other valid monitor
commands, including BIOS_FLASHER_MODE and BIOS_READ, receive status 11 (program
busy). Uploads remain
available only in the ROM menu. Sharing survives RETF, but Reset disables it.
Attach from the menu, not while an existing raw-UART program is running.
Raw UART and keyboard input share one port: in sharing mode INT 14h receive
is rejected; in raw mode it cannot consume keys already queued by INT 16h.
Do not mix the two raw input paths while a key is pending.

## INT 60h — board LCD extensions

These are board-specific functions, not replacements for DOS INT 21h.
Success clears CF; failure sets CF and AH=86h. Other flags are retained.

| AH | Inputs | Outputs / operation |
| --- | --- | --- |
| 00h | none | AX=1 revision, BX=B105h signature, CH=4 rows, CL=20 columns, DX=001Fh capabilities |
| 01h | none | Clear LCD/framebuffer and reset cursor; retain pending keyboard input |
| 02h | DH=row, DS:SI=ASCIZ | Replace one line, truncate/pad to 20 cells; cursor retained |
| 03h | AL=glyph 0..7, DS:SI=8 bytes | Load 5x8 CGRAM glyph; only low five bits of each byte used |
| 04h | DH=row, DL=column, AL=raw byte | Write one cell without interpreting controls, advancing cursor or scrolling |
| 05h | DS:SI=ASCIZ | Print string using console teletype rules |

Capabilities bits: 0 text console, 1 UART, 2 keyboard, 3 LCD extensions,
4 host keyboard sharing (cooperative polling, not an IRQ-driven keyboard).
Line/string/glyph functions preserve DS, SI and all other non-output
registers. Strings and glyph buffers belong to the caller; these calls
perform no memory isolation or bounds validation against the program image.
ASCIZ printing requires a valid terminator. After CGRAM operations BIOS
restores the LCD's DDRAM cursor.

## SDK and example

Include firmware/8088-mainboard/lib/bios_api.inc when assembling with
NASM -I lib/. It contains constants and lightweight INT macros, no LCD/UART
drivers. A macro may set argument registers before the INT; register
preservation applies to the interrupt itself, not those setup instructions.

For example:

~~~asm
BITS 16
CPU 8086
ORG 0
%include "bios_api.inc"

    bios_lcd_clear
    bios_print message
    bios_key_read
    retf

message: db 'Hello from INT!', 0
~~~

Both bundled examples use this API. The city animation loads CGRAM glyphs
through INT 60h; the UART terminal reads keys through INT 16h, echoes through
INT 14h and writes LCD cells through INT 60h.
The animation also polls INT 16h between short delay slices; Esc ends its loop.

## Verification and compatibility direction

`make test` from `firmware/8088-mainboard` runs only inside Docker. The emulator maps all four SRAM aliases
to one backing store and emulates CPU INT vector dispatch; the actual ROM
handler and IRET instructions execute in Unicorn. Tests cover vectors/BDA,
upload and memory-test isolation, caller segments/registers/flags/stack,
cursor/scrolling/CGRAM, UART status/timeout, keyboard peek/get and return.
They do not certify the board's wiring or hardware timings.

Future PC compatibility must extend the documented standard services,
memory/BDA organization, disk boot and timer/IRQ handling. This API provides
reusable implementations; it does not emulate an 80x25 display, DOS kernel
calls, PC keyboard hardware or direct PC I/O/video-memory accesses.
Standard reference: [Ralf Brown's Interrupt List](https://www.cs.cmu.edu/~ralf/files.html).

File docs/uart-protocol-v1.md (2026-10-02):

# 8088 board protocol v1

Protocol v1 defines the binary UART interface: framing, command codes,
payloads, replies and retry rules. Supported operations and valid physical
memory ranges are properties of the implementation.

UART uses 8N1; host and board must use the same configured baud rate.
boardctl uses 9600 baud. The baud rate is configured outside the protocol.
This binary protocol is separate from raw console mode. Version remains 1
during unreleased development;
update BIOS and clients together when changing this contract.

## Framing

Every packet is COBS-encoded and delimited by zero bytes:

```text
00 | COBS(decoded-frame) | 00
```

The decoded frame uses little-endian integers:

```text
version:u8 | command:u8 | sequence:u8 | length:u16 | payload | crc16:u16
```

Version is `0x01`; `length` counts payload bytes, at most 128. The common header
is five bytes; a decoded frame occupies `7 + length` bytes including CRC.
The maximum decoded size is 135 bytes, the maximum COBS body is 136 bytes,
and the maximum packet including both delimiters is 138 bytes. Consecutive
zero delimiters are allowed and do not represent empty requests.
CRC-16/CCITT-FALSE uses polynomial `0x1021`, initial `0xFFFF`, no bit reflection
and no final XOR. It covers the decoded header and payload, excluding the CRC,
COBS encoding and delimiters. The CRC is transmitted little-endian;
the check value for ASCII `123456789` is `0x29B1`.

Invalid COBS, CRC, version, declared length or payloads above 128 bytes are
ignored without a reply. An oversized packet is discarded through the next
zero delimiter. A valid frame with an invalid command payload receives that
command's error status instead.

Hosts keep one request in flight. Each new request normally increments
sequence modulo 256; retries retain the command, sequence and all payload
bytes. The board echoes sequence but does not require consecutive values or
provide a global duplicate-request cache. Retry behavior is command-specific.
Clients match both reply command and sequence and ignore unrelated frames
and interleaved console text. boardctl uses one second per response and up to
ten attempts for ordinary requests; BIOS_WRITE defaults to ten seconds per
attempt, configurable with `--timeout`. A nonzero status ends a transaction;
it is not a transport timeout and is not automatically retried by boardctl.

### Complete packet examples

All byte sequences in this section and other byte dumps are hexadecimal;
each two-digit group is one byte. CRC values are shown as integers, then
appended little-endian before COBS encoding. The wire packet includes both
zero delimiters.

PING with sequence `0x2A`, followed by its successful reply:

```text
Request header + payload: 01 01 2A 00 00
CRC16:                    0x8CEE
Decoded frame:            01 01 2A 00 00 EE 8C
COBS body:                04 01 01 2A 01 03 EE 8C
Wire packet:              00 04 01 01 2A 01 03 EE 8C 00

Reply header + payload:   01 81 2A 01 00 00
CRC16:                    0xABE4
Decoded frame:            01 81 2A 01 00 00 E4 AB
COBS body:                05 01 81 2A 01 01 03 E4 AB
Wire packet:              00 05 01 81 2A 01 01 03 E4 AB 00
```

MEMORY_READ with sequence `0x2B`, address `0x8800` and size 2. This example
assumes the target permits that RAM range and it contains bytes `AA 00`:

```text
Request header + payload: 01 07 2B 06 00 00 88 00 00 02 00
CRC16:                    0x75AF
Decoded frame:            01 07 2B 06 00 00 88 00 00 02 00 AF 75
COBS body:                05 01 07 2B 06 01 02 88 01 02 02 03 AF 75
Wire packet:              00 05 01 07 2B 06 01 02 88 01 02 02 03 AF 75 00

Reply header + payload:   01 87 2B 03 00 00 AA 00
CRC16:                    0x2E9D
Decoded frame:            01 87 2B 03 00 00 AA 00 9D 2E
COBS body:                05 01 87 2B 03 01 02 AA 03 9D 2E
Wire packet:              00 05 01 87 2B 03 01 02 AA 03 9D 2E 00
```

## Commands and replies

| Command | Value | Request payload | Result payload |
| --- | ---: | --- | --- |
| `PING` | `0x01` | empty | status |
| `INFO` | `0x02` | empty | status + ASCII information |
| `RESET` | `0x03` | empty | status; reset to ROM |
| `BIOS_FLASHER_MODE` | `0x04` | empty | status; enter BIOS flasher mode |
| `BIOS_WRITE` | `0x05` | address:u32, 1–124 image bytes | status; write and verify EEPROM |
| `BIOS_READ` | `0x06` | address:u32, size:u16 (1–127) | status + EEPROM bytes |
| `MEMORY_READ` | `0x07` | address:u32, size:u16 (1–127) | status + bytes |
| `MEMORY_WRITE` | `0x08` | address:u32, 1–124 bytes | status |
| `PROGRAM_LIST` | `0x09` | empty | status + count + records |
| `PROGRAM_UPLOAD_BEGIN` | `0x0A` | size:u32, image CRC16:u16, name | status + ID + address |
| `PROGRAM_UPLOAD_DATA` | `0x0B` | program bytes only, 1–128 | status |
| `PROGRAM_UPLOAD_COMMIT` | `0x0C` | program_id:u8 | status |
| `PROGRAM_UPLOAD_ABORT` | `0x0D` | program_id:u8 | status |
| `PROGRAM_EXEC` | `0x0E` | program_id:u8 | status; far call |
| `PROGRAM_DELETE` | `0x0F` | program_id:u8 | status |
| `PROGRAM_RENAME` | `0x10` | program_id:u8, name | status |
| `KEYBOARD_MODE` | `0x11` | enabled:u8 (0 or 1) | status + flags |
| `KEYBOARD_EVENT` | `0x12` | ASCII:u8, scan:u8 | status + flags |

Replies use `command | 0x80`, echo sequence, and start their payload
with status `0x00` for success or a nonzero error. Errors are status-only.

INFO returns status followed by human-readable ASCII without a NUL terminator.
Its text is informational, not a stable machine-readable field layout.

Unknown command codes return status 1 in the ordinary ROM monitor, 20 in
BIOS flasher mode, or 11 during cooperative program polling. Addresses and IDs are
command-specific payload fields. PROGRAM_UPLOAD_DATA contains no address; BIOS_WRITE and
BIOS_READ carry physical EEPROM addresses, just as memory commands carry RAM addresses.
For supported commands, request lengths must match the table exactly
(except variable-length names and data bytes).
Menu navigation uses KEYBOARD_EVENT; no command returns the LCD screen.

### Response statuses

The first reply payload byte is a status code. Success may include additional
command-specific data; an error reply contains only the status byte.
Numbers are decimal unless written with a `0x` prefix or included in an
explicitly hexadecimal byte dump. Numeric statuses in prose and availability
tables are decimal.

| Hex | Decimal | Status | Meaning |
| --- | ---: | --- | --- |
| `0x00` | 0 | Success | Request completed; any additional reply data follows the command contract. |
| `0x01` | 1 | Unknown command | Command is unknown in the ordinary ROM monitor. |
| `0x02` | 2 | Invalid upload request | Invalid PROGRAM_UPLOAD_BEGIN, PROGRAM_UPLOAD_COMMIT or PROGRAM_UPLOAD_ABORT request/state. |
| `0x03` | 3 | Invalid upload data | Invalid PROGRAM_UPLOAD_DATA length, bytes or transfer state. |
| `0x04` | 4 | Invalid program execution | Invalid PROGRAM_EXEC request/ID, or a pending upload prevents execution. |
| `0x05` | 5 | Invalid monitor request | Invalid PING, INFO, PROGRAM_LIST or RESET payload. |
| `0x06` | 6 | Slots full | All four program slots are occupied. |
| `0x07` | 7 | Insufficient RAM | Requested program exceeds the allocation limit or no suitable RAM range is available. |
| `0x08` | 8 | Duplicate name | Another resident program already has the requested name. |
| `0x09` | 9 | Image CRC mismatch | Complete program image does not match its expected CRC16. |
| `0x0A` | 10 | Memory check busy | Active memory check prevents this operation. |
| `0x0B` | 11 | Program busy | A running program prevents this operation; returned only when framed requests are serviced. |
| `0x0C` | 12 | Invalid keyboard request | Invalid KEYBOARD_MODE/KEYBOARD_EVENT payload, or sharing is disabled for an event. |
| `0x0D` | 13 | Keyboard queue full | Key was not accepted; the queue has no free entry. |
| `0x0E` | 14 | Invalid memory request | Invalid MEMORY_READ/MEMORY_WRITE payload or physical RAM range. |
| `0x0F` | 15 | Upload busy | Pending upload prevents BIOS_FLASHER_MODE, MEMORY_WRITE, PROGRAM_DELETE or PROGRAM_RENAME. |
| `0x10` | 16 | Invalid registry request | Invalid PROGRAM_DELETE/PROGRAM_RENAME payload or nonexistent program ID. |
| `0x11` | 17 | Unsupported operation | Operation is unavailable in this implementation or mode, as specified below. |
| `0x12` | 18 | Invalid BIOS request | Invalid BIOS_FLASHER_MODE/BIOS_READ/BIOS_WRITE payload, range or state, including a forbidden RESET. |
| `0x13` | 19 | EEPROM failure | EEPROM programming or readback verification failed; a block may be partially written. |
| `0x14` | 20 | BIOS flasher mode active | Request is outside the RAM flasher's allowed command set, including a fresh or changed mode-entry request. |

Mode and busy-state checks can take precedence over payload validation;
command-specific rules below determine which status is returned.

## Command availability

Entries assume a valid request and show either its action or a decimal error
status. A pending upload is a state within the ROM menu. The running-program
column requires sharing enabled before launch and cooperative INT `0x16`
polling; without polling, framed requests receive no reply. See
[Keyboard sharing](#keyboard-sharing) for the polling and detach rules.
In the RAM flasher, commands returning 20 perform no action.

| Command | ROM menu, no upload | Memory check | Pending program upload | Running program with sharing and polling | RAM flasher |
| --- | --- | --- | --- | --- | --- |
| `PING` | 0 | 0 | 0 | 0 | 0 |
| `INFO` | information | information | information | 11 | 20 |
| `RESET` | reset | reset | reset | 11 | reset if permitted; otherwise 18 |
| `BIOS_FLASHER_MODE` | enter | 10 | 15 | 11 | identical retry: 0; otherwise 20 |
| `BIOS_WRITE` | 17 or 18 | 17 or 18 | 17 or 18 | 17 or 11 | write/verify or 17 |
| `BIOS_READ` | 17 | 17 | 17 | 11 | EEPROM data |
| `MEMORY_READ` | RAM data | 10 | RAM data | 11 | 20 |
| `MEMORY_WRITE` | payload RAM write | 10 | 15 | 11 | 20 |
| `PROGRAM_LIST` | committed records | empty list | committed records | 11 | 20 |
| `PROGRAM_UPLOAD_BEGIN` | reserve | 10 | replace reservation | 11 | 20 |
| `PROGRAM_UPLOAD_DATA` | 3 | 3 | accept block or repeat ACK | 11 | 20 |
| `PROGRAM_UPLOAD_COMMIT` | 0 for committed ID; otherwise 2 | 2 | publish if complete and CRC matches | 11 | 20 |
| `PROGRAM_UPLOAD_ABORT` | 0 for ID=count+1; otherwise 2 | 0 for ID=1; otherwise 2 | discard for ID=count+1; otherwise 2 | 11 | 20 |
| `PROGRAM_EXEC` | launch committed ID | 4 | 4 | 11 | 20 |
| `PROGRAM_DELETE` | delete committed ID | 10 | 15 | 11 | 20 |
| `PROGRAM_RENAME` | rename committed ID | 10 | 15 | 11 | 20 |
| `KEYBOARD_MODE` | set sharing | set sharing | set sharing | set sharing | 20 |
| `KEYBOARD_EVENT` | accept key if sharing enabled | accept key if sharing enabled | accept key if sharing enabled | accept key | 20 |
| Unknown command | 1 | 1 | 1 | 11 | 20 |

Memory check clears all registry entries and pending uploads before testing,
which explains the empty list and upload/execution results in that column.
Key acceptance remains subject to queue capacity; menu actions can change
state. Upload completion, valid IDs and names follow the command contracts below.

For BIOS_WRITE, status 17 means writing is unsupported. When writing is
supported, requests outside the flasher return 18, or 11 while a program runs.
In the flasher, invalid BIOS_READ/BIOS_WRITE payloads or ranges return 18;
a valid unsupported write returns 17. Supported writes return 0 after
verification, or 19 on programming/readback failure.
RESET permission in the flasher is defined in [Exit and recovery](#exit-and-recovery).

Mode and busy-state restrictions can take precedence over payload validation.
Outside the flasher, BIOS_READ returns 17 without payload validation, except
while a program runs, when it returns 11. Unsupported BIOS_WRITE outside the
flasher returns 17 without payload validation. BIOS_FLASHER_MODE during an
upload returns 15 even for an invalid payload. Other malformed requests follow
their command-specific status rules; invalid PING/INFO/PROGRAM_LIST/RESET
payloads in the ordinary monitor return 5.

## Retry reference

Transport retries reuse the command, sequence and every payload byte. This
table summarizes behavior; detailed recovery rules remain in each command's
section. There is no global duplicate-request cache, and an eight-bit sequence
number does not identify a session. BIOS_WRITE caching and recovery in this
table apply when EEPROM writing is supported.

| Command | Effect of an identical retry | Cache lifetime or recovery condition |
| --- | --- | --- |
| `PING` | Replies again. | No cached result. |
| `INFO` | Generates current information again. | No snapshot cache. |
| `RESET` | Resets again if the current mode permits it. | Reset clears registry and sharing state; a lost ACK does not imply reset failed. |
| `BIOS_FLASHER_MODE` | In the flasher, repeats the entry ACK without copying or restarting. | Entry sequence must match and payload must be empty; fresh or changed entry returns 20. |
| `BIOS_WRITE` | Repeats the last successful result without programming again; the same sequence after a failed attempt repeats its failure. | Unrelated requests do not clear the cache. A new sequence permits retry of a failed programming block. After a complete transfer, a WRITE at `0xF8000` with a sequence different from the last WRITE starts a new transfer. See [Writing EEPROM blocks](#writing-eeprom-blocks). |
| `BIOS_READ` | Reads EEPROM again. | No snapshot cache; transfer progress and WRITE cache are preserved. |
| `MEMORY_READ` | Reads RAM again. | No snapshot cache. |
| `MEMORY_WRITE` | Writes the same bytes to the same address again. | No transaction cache or rollback. |
| `PROGRAM_LIST` | Reads the current registry again. | No snapshot cache. |
| `PROGRAM_UPLOAD_BEGIN` | Replaces the pending reservation and starts it again. | Retry only before DATA; a successful BEGIN clears the DATA cache. |
| `PROGRAM_UPLOAD_DATA` | Repeats the last accepted block's ACK without advancing; changed bytes with that sequence return 3. | Successful BEGIN, COMMIT and ABORT clear the cache; rejected requests preserve it. |
| `PROGRAM_UPLOAD_COMMIT` | Already committed ID is a no-op if no upload is pending. | CRC failure leaves the upload pending; ABORT or a new BEGIN discards/replaces it. |
| `PROGRAM_UPLOAD_ABORT` | No-op without a pending upload, provided ID=count+1. | Successful ABORT clears the DATA cache. |
| `PROGRAM_EXEC` | Same sequence/ID repeats ACK without launching again once serviced by the ROM menu. | Any non-EXEC command handled by the ROM menu clears the cache; send PING before an intentional new launch. |
| `PROGRAM_DELETE` | Same sequence/ID repeats ACK without deleting the next program. | Any non-DELETE command handled by the ROM menu clears the cache; send PING before an intentional new deletion. |
| `PROGRAM_RENAME` | Applies the same name again. | Harmless while the ID still refers to that program. |
| `KEYBOARD_MODE` | Repeated mode preserves the queue. | Mode transitions clear the queue and EVENT retry cache. |
| `KEYBOARD_EVENT` | Last accepted sequence/data repeats ACK without enqueueing or navigating twice. | A newly accepted event replaces the cache; mode transitions and Reset clear it. A full queue returns 13 without accepting the event. |

## BIOS flasher mode

BIOS_FLASHER_MODE copies the built-in EEPROM flasher to RAM. Command
availability and unsupported-operation statuses are listed in
[Command availability](#command-availability). BIOS_WRITE programs EEPROM
when writing is supported.
No complete BIOS image is staged in RAM: only the BIOS flasher, its state,
stack and packet/block buffers need memory. boardctl exposes `bios-flasher-mode`,
`bios-read` and `bios-write`; see its [EEPROM guide](../tools/boardctl/README.md#bios-flasher-mode).

The programming, WRITE retry-cache and RESET rules below apply when EEPROM
writing is supported. After EEPROM writing begins, RESET requires a complete
transfer verified by readback.

### Entering BIOS flasher mode

BIOS_FLASHER_MODE accepts an empty payload. The EEPROM image size is fixed at
32,768 bytes and is not transmitted. Entering the mode permits full EEPROM
replacement, including boot code and reset vector, if writing is available;
entry itself writes nothing. Read-only clients simply never send BIOS_WRITE.

The ROM BIOS copies its self-contained BIOS flasher into payload RAM and
transfers control to it. All code, constants, state, buffers, stack and used
handlers are in RAM. The monitor owns UART, uses polling with hardware
interrupts disabled and makes no calls into ROM BIOS. It preserves UART
configuration and queued RX bytes. The FLASHER_MODE success reply is generated only
once the RAM monitor is ready to receive requests.

Entry restrictions follow [Command availability](#command-availability).
Invalid payload length returns 18 when entry is otherwise permitted.
Failed entry preserves programs and uploads. Successful entry clears the
resident program registry and keyboard sharing/queue because the RAM monitor
may overwrite program memory. It does not run the ROM menu or Memory check.
The flasher is embedded in the BIOS; no host upload of its program is needed.

An identical FLASHER_MODE retry with the same sequence and empty payload
repeats its ACK from RAM without copying again or changing progress. This
lost-ACK retry is the only exception to the RAM-flasher command set. Fresh
FLASHER_MODE requests or non-empty payloads return 20; they cannot restart or
switch the active mode.

Sequence is only eight bits, so a new client can reuse an earlier entry's
sequence. An entry ACK alone therefore cannot prove a fresh session.
To inspect the current mode, send BIOS_READ at `0xF8000` with
size 1: status 17 means the ordinary monitor; status 0 plus one byte means the RAM flasher.
Other statuses remain errors. boardctl probes before automatic entry: it can
read from an existing flasher, but rejects a new write into that active session.

### Writing EEPROM blocks

BIOS_WRITE accepts 5–128 payload bytes: physical `address:u32` followed by
1–124 image bytes. The entire block must lie in the canonical EEPROM window
`0xF8000..0xFFFFF`; RAM, EEPROM mirrors and unmapped addresses are rejected.
Addresses never wrap or truncate to 20 bits. Invalid length/range returns 18
before any write; mode and support checks follow the availability table.
Hosts send consecutive blocks starting at `0xF8000`, keep one request in flight
and wait for its reply before sending another.
On writing firmware, empty data, gaps, overlaps, overflow and out-of-range
blocks return 18 before any byte is written; the last accepted block retry and
restart after completion are the exceptions below.

The programmer validates the complete frame and block before writing. It
splits writes at EEPROM page boundaries, waits for each programming cycle
using the device's completion polling, and checks every written byte by
readback. Block success is sent only after verification; failure returns 19
and may leave part of that block programmed. The host may choose 64-byte
aligned blocks for AT28C256, but the wire limit remains 124 image bytes.

The programmer retains the last attempted block's address, bytes and result.
After success, an identical retry returns the saved ACK without programming
again or advancing progress twice, regardless of sequence wrap. Changed bytes
at that address return 18. After a programming failure, an identical retry with
the same sequence repeats the failure; a different sequence permits another
attempt at that failed address.
No unrelated request clears the WRITE retry cache.

The last WRITE returns success after that block has been programmed and
verified by readback, completing the full 32-KiB transfer. After completion,
an identical last-block retry still returns its saved result. A valid WRITE
at `0xF8000` with a sequence different from the last attempted WRITE explicitly
starts a new full transfer, even if its bytes match the previous image. Other
new blocks return 18. The programmer validates this first block before
changing state, then clears completion and the old WRITE cache, sets progress
to zero and programs the block normally. RESET is blocked from that point
until the new full transfer completes, including if this first write fails.
A lost restart ACK is handled by the normal last-block retry rules; retries
never restart the transfer twice. The RAM flasher remains active throughout;
no BIOS_FLASHER_MODE or RESET is sent to restart a transfer.

No COMMIT or separate final flashing command is needed. Clients must allow
time for programming and readback; the ordinary
one-second monitor timeout is not a completion deadline.
A timeout does not cancel a write. If its outcome is unknown, retry the exact
same request; do not assume the EEPROM or transfer cursor remained unchanged.

### Reading EEPROM and comparing hashes

BIOS_READ accepts exactly six payload bytes: physical `address:u32, size:u16`.
Success returns exactly `status=0x00` followed by the requested 1–127 bytes.
The complete range must lie in the canonical EEPROM window `0xF8000..0xFFFFF`.
Invalid lengths/sizes, RAM, EEPROM mirrors, unmapped addresses, overflow or
ranges crossing the window boundary return 18 before any read. Addresses never
truncate to 20 bits or wrap.

For example, these are decoded request payloads before frame CRC and COBS:

| Request | Payload bytes in hex | RAM-flasher result |
| --- | --- | --- |
| READ `0xF8000`, 127 bytes | `00 80 0F 00 7F 00` | status 0 + 127 EEPROM bytes |
| READ `0xFFFFF`, 1 byte | `FF FF 0F 00 01 00` | status 0 + last EEPROM byte |
| READ `0xFFFFF`, 2 bytes | `FF FF 0F 00 02 00` | status 18, no read |
| WRITE `0xF8000`, byte `0xAA` | `00 80 0F 00 AA` | valid range; status 17 if writing is unsupported |
| WRITE RAM `0x8800`, byte `0xAA` | `00 88 00 00 AA` | status 18, no write |

READ is available from the RAM programmer after BIOS_FLASHER_MODE while
waiting for requests, including before flashing, after the final block and
after a failed write. The programmer must finish any EEPROM
programming cycle before serving a read. READ reads the actual EEPROM,
not the copied monitor or an image buffer. It does not write EEPROM, change
transfer progress, clear the WRITE retry cache or start the new BIOS.

The host reads the full 32-KiB image in chunks and compares its SHA-256 with
that of the source file, including padding and reset vector, before sending
RESET. SHA-256 is computed on the host; the wire reply contains bytes, not a
hash. This check complements the programmer's per-block readback verification.
Chunked reads are not an atomic snapshot: do not send WRITE between chunks
when comparing the image. Repeating READ reads EEPROM again.

If SHA-256 does not match, the host must not send RESET. It may repeat the
complete read to confirm the mismatch, then start a new full transfer using
the WRITE restart rule above, write all 32 KiB and compare SHA-256 again.
The flasher cannot detect a host-side hash mismatch: its RESET permission
reflects only completed writes and per-block readback, so the host must enforce
this check. The current boardctl reports a mismatch and leaves the flasher
active; starting another transfer in an active flasher is not yet exposed by
its CLI.

### Exit and recovery

RESET is available before any EEPROM write or after complete successful
verification. If writing is unsupported, a valid RESET is always permitted.
When writing is supported, RESET after a partial/failed write
returns 18 until all 32,768 image bytes have been written and verified by
readback. Invalid PING/RESET payloads return 5. A successful RESET sends an ACK, waits for UART TX to drain
and starts the ROM BIOS at `0xF800:0x0000`; registry and sharing state are reset.
Firmware gates RESET on completion of the full transfer and per-block readback
verification. It does not receive or compute the host's SHA-256 comparison.
Perform the host comparison described in
[Reading EEPROM and comparing hashes](#reading-eeprom-and-comparing-hashes)
before resetting after flashing. There is no automatic reset after the final WRITE.

Once EEPROM has been changed, the RAM monitor must remain active after errors
or host disconnection. Retrying writes permits recovery without returning to
incomplete ROM; it provides no rollback. Power loss or hardware Reset during
writing can require an external programmer or an independently preserved
recovery loader.

## RAM reads and writes

MEMORY_READ returns exactly `status=0x00` followed by the requested 1–127 bytes.
The entire range must lie in the board's configured RAM address space.
Clients must use the target implementation's memory map, including any RAM
aliases. The protocol does not prescribe RAM capacity or its address layout.
ROM, unmapped addresses, ranges crossing the RAM boundary,
sizes outside 1–127 and payload lengths other than 6 return status 14.
Addresses never wrap or truncate to 20 bits. EEPROM reads use BIOS_READ after
entering BIOS flasher mode.
Reads include IVT, BDA and BIOS state but do not write the requested memory;
normal UART packet buffers, BIOS stack and live state still change during
handling. Chunked dumps are not atomic snapshots. Retries read again, not a
cached snapshot. Mode restrictions follow the availability table.

MEMORY_WRITE accepts payload lengths 5–128: address followed by 1–124 bytes.
The complete range is checked before any byte is written. Only the firmware's
payload/program RAM is writable. The implementation defines its writable
ranges and protects reserved memory through every physical alias. IVT/BDA, BIOS/API
state, stacks, ROM and unmapped regions are rejected with status 14, including
ranges crossing a protected boundary. Mode restrictions follow the availability
table. Retrying a write overwrites the same address with the same bytes.
Raw writes do not allocate or register programs and may modify resident program
code. Multi-packet writes are not transactional and provide no rollback.

## Upload and program registry

BEGIN/DATA/COMMIT/ABORT below abbreviate the PROGRAM_UPLOAD_* commands.

The registry has four slots. Programs occupy the implementation's payload RAM;
BIOS state and stacks remain reserved. BEGIN returns the chosen physical address.
Allocation is first-fit, aligned upward to 16 bytes. Deleted ranges are reused;
resident program bytes are never moved. Fragmentation can prevent an allocation
even when the total free byte count would suffice.
Use BIOS's reply rather than assuming a fixed allocation address.

BEGIN names are 1–15 printable ASCII bytes (`0x20`..`0x7E`), not all spaces,
case-sensitive and unique among committed programs. No name terminator;
total request data length is 7–21 bytes. Image CRC uses the frame CRC algorithm
over the entire binary. Success returns
`status:u8, ID:u8, physical_address:u32` (6 bytes).
Although BEGIN carries size:u32, each program must be 1–65,535 bytes because
PROGRAM_LIST carries size:u16 and the program ABI uses a 16-bit segment.
The implementation's allocation limit can be smaller. Zero or a nonzero high
16-bit word returns 2; insufficient payload RAM or a firmware allocation limit
returns 7 (or 6 if all slots are occupied).

Successful BEGIN replaces any pending reservation without touching committed programs.
It is not globally deduplicated: retrying BEGIN starts the reservation again.
Retry it only before sending DATA; a rejected BEGIN preserves the previous upload.
Only committed programs occupy allocation ranges. DATA contains only program bytes;
BIOS maintains the write address and received byte count inside the reservation.
Each block must contain exactly 128 bytes, except the last block, which must
contain all remaining bytes (1–128). Hosts keep only one request in flight and
wait for its ACK before sending the next block. Retrying the last accepted DATA
with the same sequence and identical bytes repeats its ACK without writing or
counting twice; changed bytes with that sequence return status 3.
Sequence wraps from 255 to 0 and is not a block index. Successful BEGIN, COMMIT
and ABORT clear the DATA retry cache. Rejected requests, including a failed
COMMIT CRC check, do not clear it. No additional new block is accepted after completion.

COMMIT publishes only after all declared bytes arrive and image CRC matches.
COMMIT of an already committed ID is a no-op when no upload is pending.
CRC mismatch returns 9 and leaves the upload pending; use ABORT or a new BEGIN
to discard or replace it. Already accepted DATA cannot be patched by resending
different bytes with its old sequence.
ABORT requires ID=count+1; repeating it without a pending upload is a no-op.
Neither command clears resident programs.

PROGRAM_EXEC rejects pending uploads and accepts only committed IDs (1..count).
Immediate retries of the same sequence/ID do not execute twice; any non-PROGRAM_EXEC
command handled by the ordinary ROM menu clears this cache. Send PING from
the menu before a new intentional launch.
RESET clears all registry metadata.

PROGRAM_LIST returns `status:u8, count:u8`, then count 23-byte records:
`ID:u8, physical_address:u32, size:u16, name[16]`. Names are NUL-terminated
and zero-padded; IDs are consecutive 1..count. Pending entries are excluded.
Records are ID-ordered, not necessarily address-ordered after hole reuse.

PROGRAM_DELETE removes a committed ID and frees its slot and RAM range without
moving or zeroing any program bytes. Following IDs shift down by one; refresh
PROGRAM_LIST before using saved IDs. The LCD switches to Custom programs.
Immediate retries with the same sequence/ID are acknowledged without deleting
the next program. Any non-PROGRAM_DELETE command clears this retry cache; send
PING before a new intentional deletion (boardctl does this automatically).

PROGRAM_RENAME changes only the name of a committed ID. Names obey the same
rules as BEGIN; the name may remain unchanged, but must not match another
resident's name. Request payload length is 2–16 bytes. Address, size and program
bytes are preserved, and the LCD is refreshed. Repeating the rename is harmless.
Both commands return status 16 for malformed payloads/nonexistent IDs, 15 during
pending uploads, 10 during memory checks, or 11 from a polling running program.
Duplicate names return status 8.

## Keyboard sharing

Attach with KEYBOARD_MODE data `0x01` from the ROM menu before launching a
program; `0x00` detaches. Mode transitions clear the key queue and retry cache;
repeated attachment preserves keys. Reset disables sharing; RETF preserves
sharing but clears pending keys and UART RX.

Successful mode/event replies are exactly `status=0x00, flags:u8`.
Bit 0 indicates a running program or a menu key about to launch one after the
reply drains; all other bits are zero. No LCD data is included.

Events require `(ASCII != 0 || scan != 0)`, with ASCII in `0x00`..`0x7F`.
ASCII with scan=0 is translated by BIOS where supported. Extended keys use
ASCII=0, scan!=0 (Up=`0x48`, Down=`0x50`, Left=`0x4B`, Right=`0x4D`).
The menu consumes Enter, Esc, Up and Down from the shared 15-key BDA ring;
other keys have no menu action. Retrying the last accepted sequence/data
does not enqueue or navigate twice. Status 13 means the key was not accepted.

The protocol guarantees framed replies in the ROM menu and RAM flasher.
Enable sharing before launching a program. Framed traffic while it runs
requires the BIOS to service UART requests. Cooperative implementations do
this through INT `0x16`/AH=`0x00` or AH=`0x01` calls with sharing enabled.
The accepted subset and busy/unsupported replies are listed in
[Command availability](#command-availability). Without regular polling,
requests receive no reply and UART FIFO overflow is possible.
Protocol v1 does not require background command handling while a program owns
the board. Clients
must wait for return unless that firmware provides the cooperative subset.
Sharing owns UART RX: raw INT `0x14` receive is rejected; TX/status still work.
Detaching with KEYBOARD_MODE=0 while a program runs stops framed polling;
subsequent INT `0x16` reads use raw UART input until program return or Reset.
Only one host process may own the UART. Reconnect after Reset; Reset also
recovers raw mode if detach cannot be acknowledged.

## Runtime availability

PROGRAM_EXEC and menu launches transfer control after their reply drains.
Stop ordinary monitor requests until `8088 ROM monitor ready\r\n` announces
return/reset; clients must tolerate ASCII text between frames. The cooperative
keyboard polling subset above is the only exception while a program runs.
RETF preserves committed programs.

Confirmed Memory check invalidates all programs and pending uploads;
cancellation does not restore them. During testing UART remains polled:
keyboard, PING and INFO requests work, but uploads and launches cannot run.

## Related documentation

- [BIOS API and program ABI](../firmware/8088-mainboard/docs/bios-api.md):
  binary format, entry registers, stacks, memory aliases and INT services.
- [BIOS interface](../firmware/8088-mainboard/README.md#boot-menu) and
  [Memory check](../firmware/8088-mainboard/README.md#memory-check): menu,
  LCD layout, progress and diagnostic details.
- [boardctl keyboard](../tools/boardctl/README.md#keyboard-sharing): host
  shortcuts, upload prompt and connection instructions.

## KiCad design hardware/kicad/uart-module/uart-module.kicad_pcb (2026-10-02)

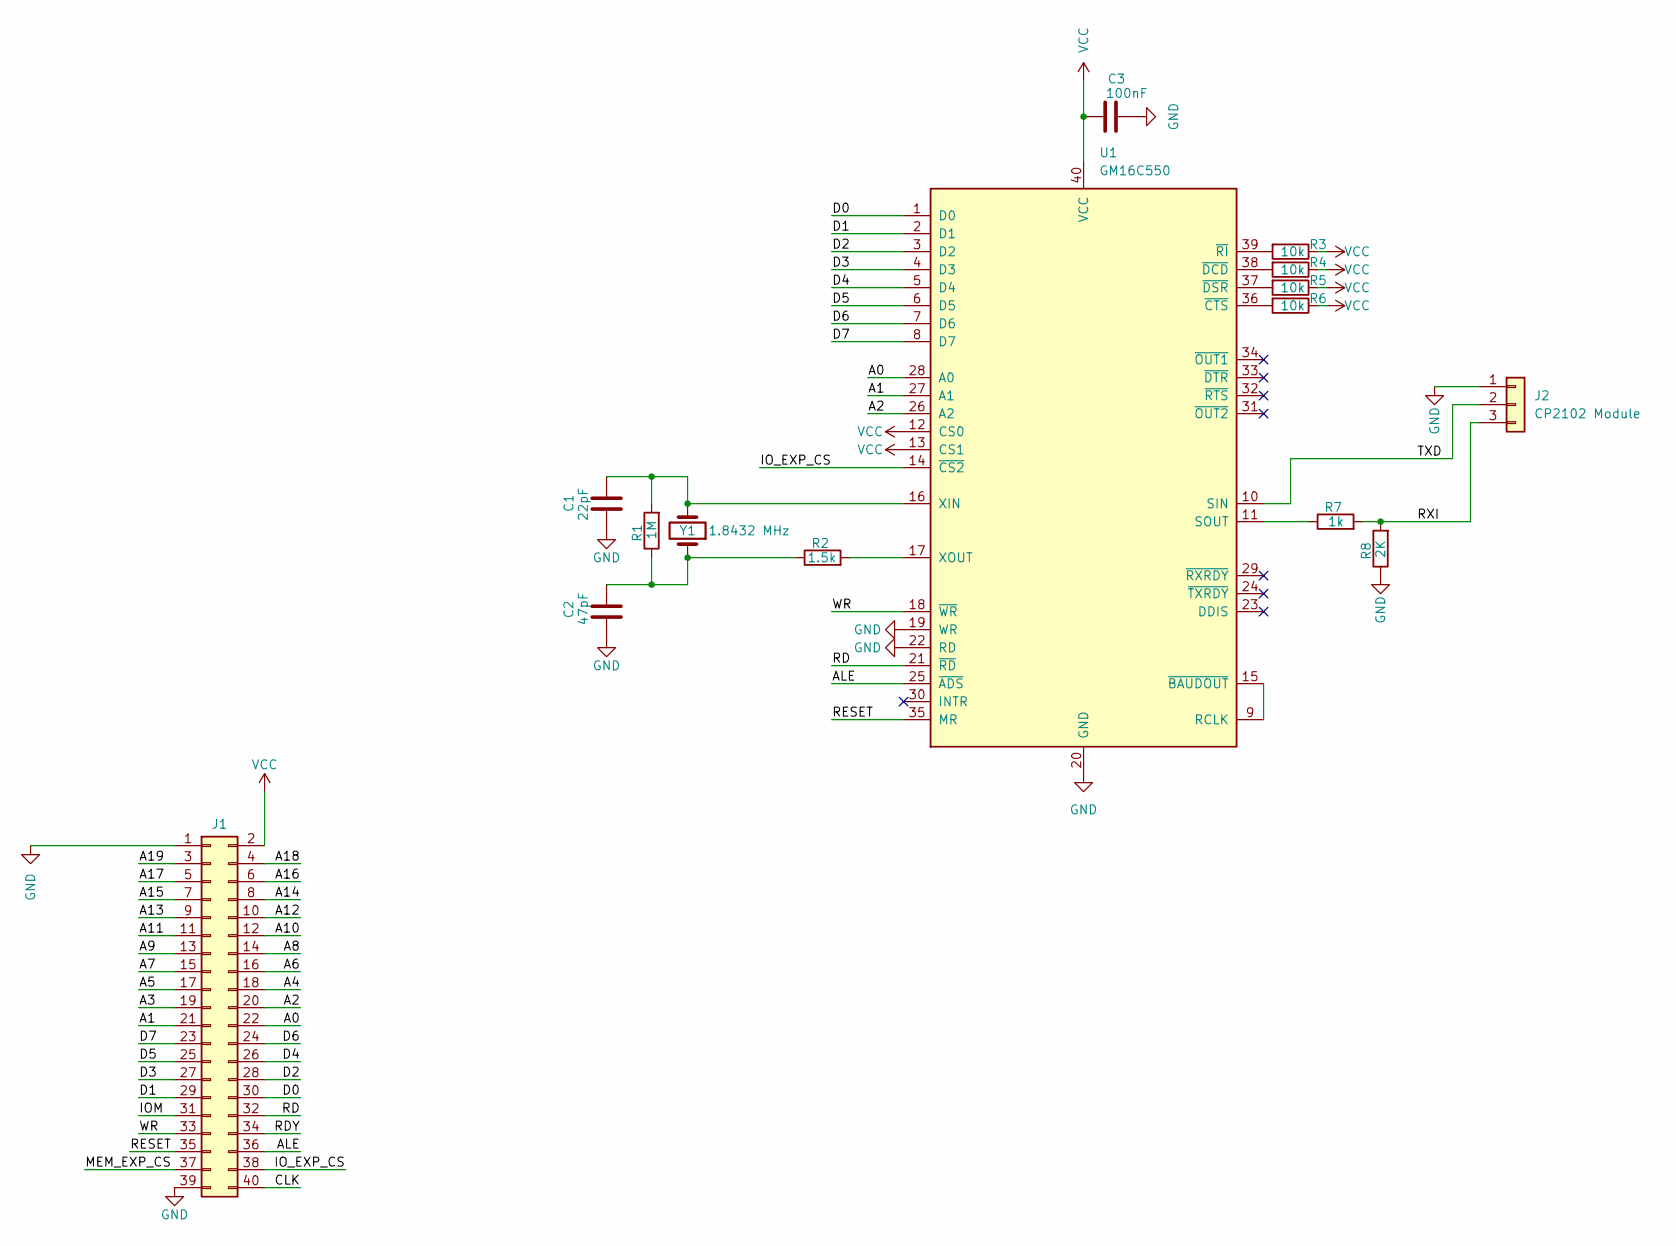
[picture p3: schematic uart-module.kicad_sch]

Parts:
C1: 22pF; C_Disc_D5.0mm_W2.5mm_P5.00mm
C2: 47pF; C_Disc_D5.0mm_W2.5mm_P5.00mm
C3: 100nF; C_Disc_D5.0mm_W2.5mm_P5.00mm
J1: Exp0; PinSocket_2x20_P2.54mm_Vertical
J2: CP2102 Module; PinHeader_1x03_P2.54mm_Vertical
R1: 1M; R_Axial_DIN0207_L6.3mm_D2.5mm_P7.62mm_Horizontal
R2: 1.5k; R_Axial_DIN0207_L6.3mm_D2.5mm_P7.62mm_Horizontal
R3, R4, R5, R6: 10k; R_Axial_DIN0207_L6.3mm_D2.5mm_P7.62mm_Horizontal
R7: 1k; R_Axial_DIN0207_L6.3mm_D2.5mm_P7.62mm_Horizontal
R8: 2K; R_Axial_DIN0207_L6.3mm_D2.5mm_P7.62mm_Horizontal
U1: GM16C550; DIP-40_W15.24mm
Y1: 1.8432 MHz; Crystal_HC49-U_Vertical

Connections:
/A0: J1.22, U1.28 (A0)
/A1: J1.21, U1.27 (A1)
/A2: J1.20, U1.26 (A2)
/A3: J1.19
/A4: J1.18
/A5: J1.17
/A6: J1.16
/A7: J1.15
/A8: J1.14
/A9: J1.13
/A10: J1.12
/A11: J1.11
/A12: J1.10
/A13: J1.9
/A14: J1.8
/A15: J1.7
/A16: J1.6
/A17: J1.5
/A18: J1.4
/A19: J1.3
/ALE: J1.36, U1.25 (~ADS)
/CLK: J1.40
/D0: J1.30, U1.1 (D0)
/D1: J1.29, U1.2 (D1)
/D2: J1.28, U1.3 (D2)
/D3: J1.27, U1.4 (D3)
/D4: J1.26, U1.5 (D4)
/D5: J1.25, U1.6 (D5)
/D6: J1.24, U1.7 (D6)
/D7: J1.23, U1.8 (D7)
/IOM: J1.31
/IO_EXP_CS: J1.38, U1.14 (~CS2)
/MEM_EXP_CS: J1.37
/RD: J1.32, U1.21 (~RD)
/RDY: J1.34
/RESET: J1.35, U1.35 (MR)
/RXI: J2.3, R7.2, R8.2
/TXD: J2.2, U1.10 (SIN)
/WR: J1.33, U1.18 (~WR)
GND: C1.1, C2.1, C3.2, J1.1, J1.39, J2.1, R8.1, U1.19 (WR), U1.20 (GND), U1.22 (RD)
unnamed: C2.2, R1.1, R2.1, Y1.1
unnamed: U1.9 (RCLK), U1.15 (~BAUDOUT)
unnamed: R7.1, U1.11 (SOUT)
unnamed: C1.2, R1.2, U1.16 (XIN), Y1.2
unnamed: R2.2, U1.17 (XOUT)
unnamed: R6.2, U1.36 (~CTS)
unnamed: R4.2, U1.38 (~DCD)
unnamed: R5.2, U1.37 (~DSR)
unnamed: R3.2, U1.39 (~RI)
VCC: C3.1, J1.2, R3.1, R4.1, R5.1, R6.1, U1.12 (CS0), U1.13 (CS1), U1.40 (VCC)

Board: 2 copper layers, 15 parts (2 on the bottom side), 29 nets, no tracks yet.

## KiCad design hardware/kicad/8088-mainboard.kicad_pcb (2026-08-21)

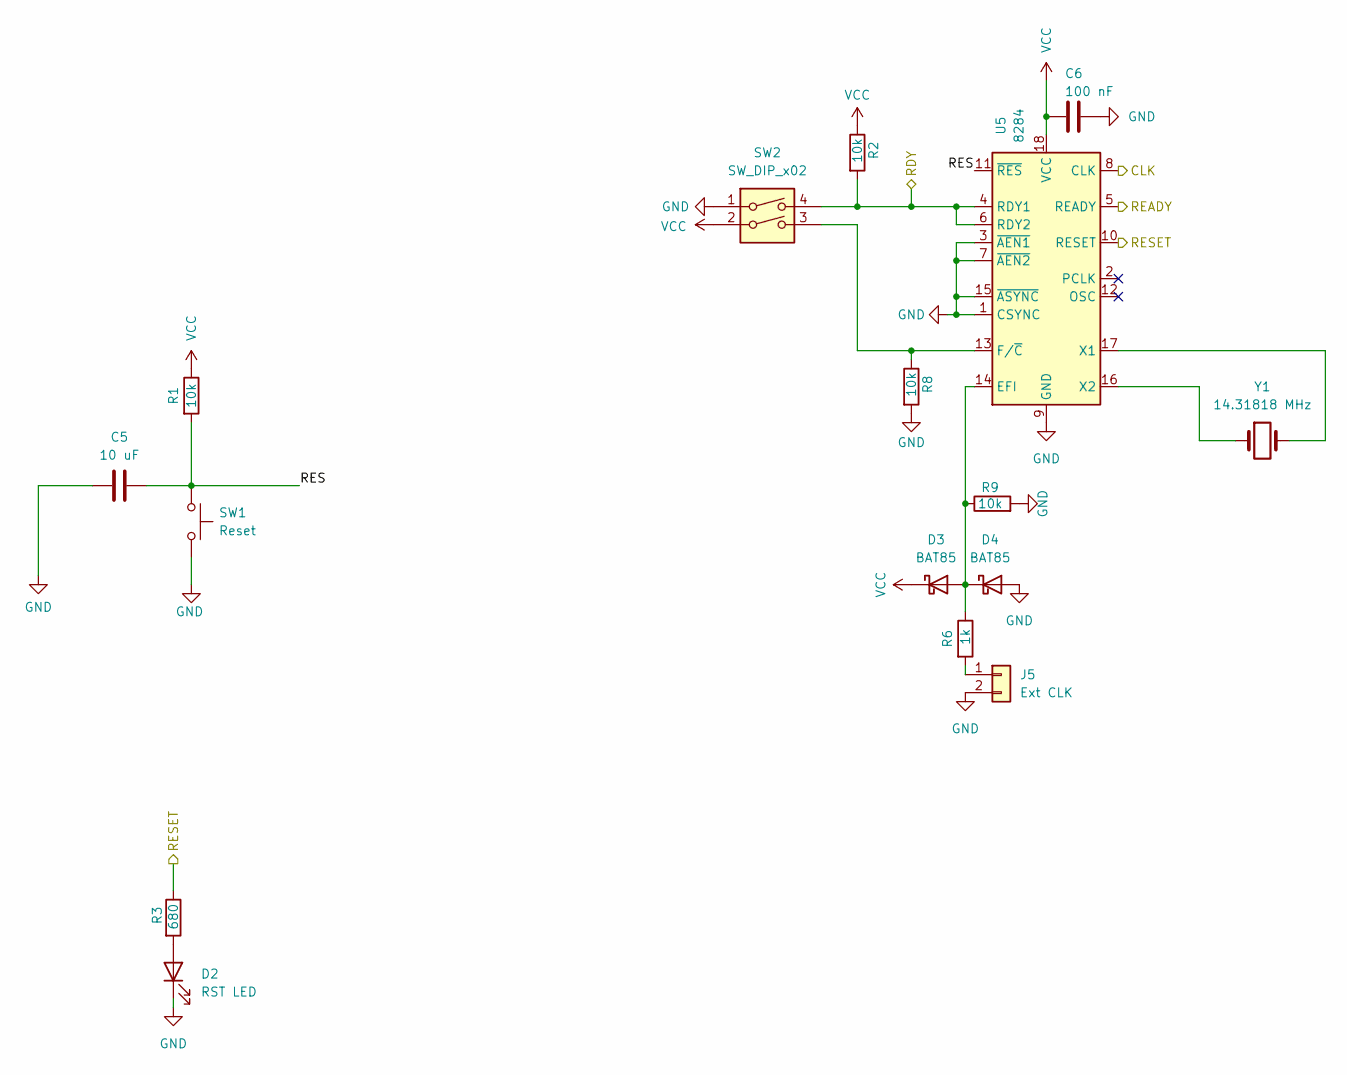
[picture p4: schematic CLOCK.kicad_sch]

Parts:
C5: 10 uF; CP_Radial_D4.0mm_P1.50mm
C6: 100 nF; C_Disc_D5.0mm_W2.5mm_P5.00mm
D2: RST LED; LED_D3.0mm
D3, D4: BAT85; D_DO-35_SOD27_P7.62mm_Horizontal
J5: Ext CLK; PinHeader_1x02_P2.54mm_Vertical
R1, R2, R8, R9: 10k; R_Axial_DIN0207_L6.3mm_D2.5mm_P7.62mm_Horizontal
R3: 680; R_Axial_DIN0207_L6.3mm_D2.5mm_P7.62mm_Horizontal
R6: 1k; R_Axial_DIN0207_L6.3mm_D2.5mm_P7.62mm_Horizontal
SW1: Reset; SW_PUSH_6mm
SW2: SW_DIP_x02; SW_DIP_SPSTx02_Slide_9.78x7.26mm_W7.62mm_P2.54mm
U5: 8284; DIP-18_W7.62mm_Socket
Y1: 14.31818 MHz; Crystal_HC49-U_Vertical

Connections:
/CLK: U5.8 (CLK); also elsewhere on the board
/CLOCK/RES: C5.1, R1.2, SW1.1, U5.11 (~RES)
/RDY: R2.2, SW2.4, U5.4 (RDY1), U5.6 (RDY2); also elsewhere on the board
/READY: U5.5 (READY); also elsewhere on the board
/RESET: R3.1, U5.10 (RESET); also elsewhere on the board
GND: C5.2, C6.2, D2.1 (K), D4.2 (A), J5.2, R8.2, R9.2, SW1.2, SW2.1, U5.1 (CSYNC), U5.3 (~AEN1), U5.7 (~AEN2), U5.9 (GND), U5.15 (~ASYNC); also elsewhere on the board
unnamed: D2.2 (A), R3.2
unnamed: D3.2 (A), D4.1 (K), R6.1, R9.1, U5.14 (EFI)
unnamed: J5.1, R6.2
unnamed: R8.1, SW2.3, U5.13 (F/~C)
unnamed: U5.17 (X1), Y1.2
unnamed: U5.16 (X2), Y1.1
VCC: C6.1, D3.1 (K), R1.1, R2.1, SW2.2, U5.18 (VCC); also elsewhere on the board

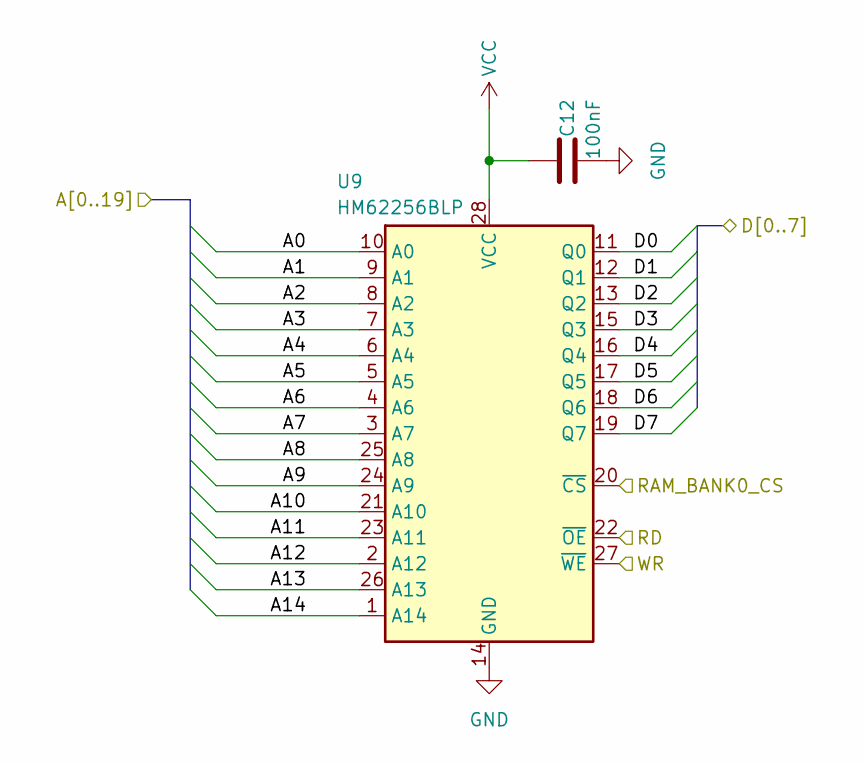
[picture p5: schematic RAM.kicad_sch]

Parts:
C12: 100nF; C_Disc_D5.0mm_W2.5mm_P5.00mm
U9: HM62256BLP; DIP-28_W15.24mm_Socket

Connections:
/A0: U9.10 (A0); also elsewhere on the board
/A1: U9.9 (A1); also elsewhere on the board
/A2: U9.8 (A2); also elsewhere on the board
/A3: U9.7 (A3); also elsewhere on the board
/A4: U9.6 (A4); also elsewhere on the board
/A5: U9.5 (A5); also elsewhere on the board
/A6: U9.4 (A6); also elsewhere on the board
/A7: U9.3 (A7); also elsewhere on the board
/A8: U9.25 (A8); also elsewhere on the board
/A9: U9.24 (A9); also elsewhere on the board
/A10: U9.21 (A10); also elsewhere on the board
/A11: U9.23 (A11); also elsewhere on the board
/A12: U9.2 (A12); also elsewhere on the board
/A13: U9.26 (A13); also elsewhere on the board
/A14: U9.1 (A14); also elsewhere on the board
/D0: U9.11 (Q0); also elsewhere on the board
/D1: U9.12 (Q1); also elsewhere on the board
/D2: U9.13 (Q2); also elsewhere on the board
/D3: U9.15 (Q3); also elsewhere on the board
/D4: U9.16 (Q4); also elsewhere on the board
/D5: U9.17 (Q5); also elsewhere on the board
/D6: U9.18 (Q6); also elsewhere on the board
/D7: U9.19 (Q7); also elsewhere on the board
/MEM_DECODER/RAM_BANK0_CS: U9.20 (~CS); also elsewhere on the board
/RD: U9.22 (~OE); also elsewhere on the board
/WR: U9.27 (~WE); also elsewhere on the board
GND: C12.2, U9.14 (GND); also elsewhere on the board
VCC: C12.1, U9.28 (VCC); also elsewhere on the board

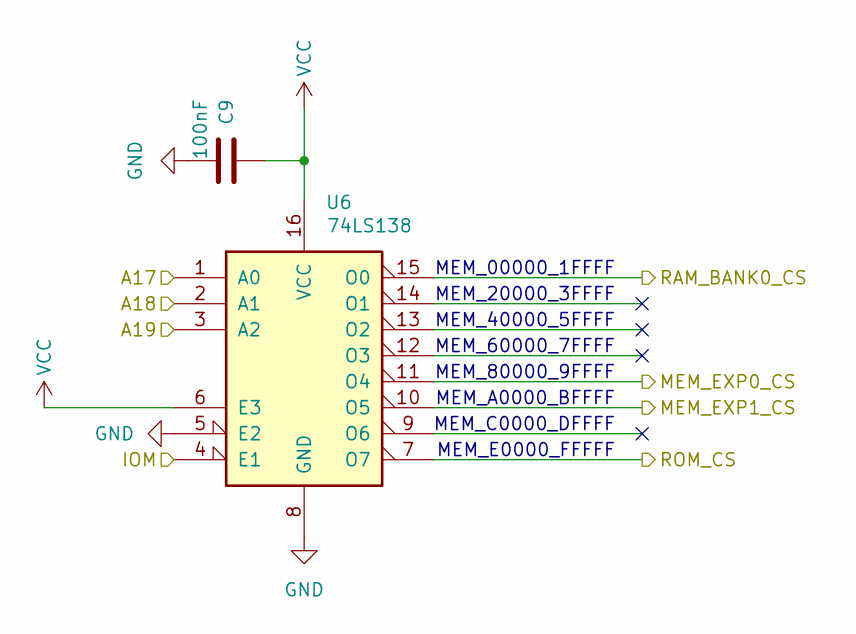
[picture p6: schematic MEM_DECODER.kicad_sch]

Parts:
C9: 100nF; C_Disc_D5.0mm_W2.5mm_P5.00mm
U6: 74LS138; DIP-16_W7.62mm_Socket

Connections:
/A17: U6.1 (A0); also elsewhere on the board
/A18: U6.2 (A1); also elsewhere on the board
/A19: U6.3 (A2); also elsewhere on the board
/EXPANSION_CONNECTOR/MEM_EXP0_CS: U6.11 (O4); also elsewhere on the board
/EXPANSION_CONNECTOR/MEM_EXP1_CS: U6.10 (O5); also elsewhere on the board
/IOM: U6.4 (E1); also elsewhere on the board
/MEM_DECODER/RAM_BANK0_CS: U6.15 (O0); also elsewhere on the board
/MEM_DECODER/ROM_CS: U6.7 (O7); also elsewhere on the board
GND: C9.2, U6.5 (E2), U6.8 (GND); also elsewhere on the board
VCC: C9.1, U6.6 (E3), U6.16 (VCC); also elsewhere on the board

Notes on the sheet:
MEM_80000_9FFFF
MEM_60000_7FFFF
MEM_20000_3FFFF
MEM_E0000_FFFFF
MEM_40000_5FFFF
MEM_A0000_BFFFF
MEM_00000_1FFFF
MEM_C0000_DFFFF

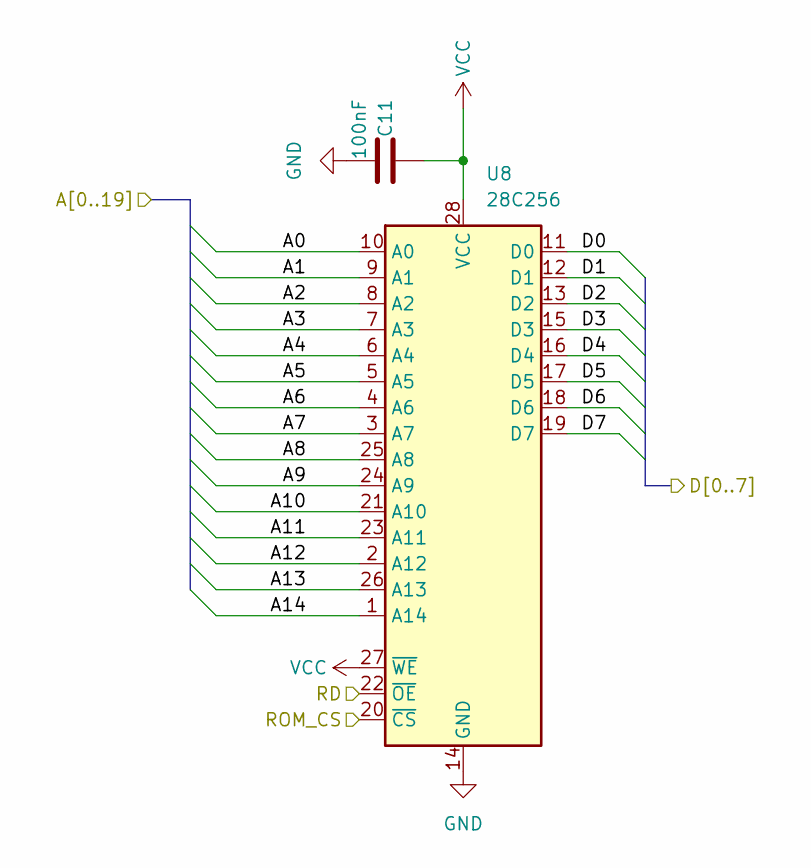
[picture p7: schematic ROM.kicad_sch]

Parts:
C11: 100nF; C_Disc_D5.0mm_W2.5mm_P5.00mm
U8: 28C256; DIP_Socket-28_W11.9mm_W12.7mm_W15.24mm_W17.78mm_W18.5mm_3M_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

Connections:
/A0: U8.10 (A0); also elsewhere on the board
/A1: U8.9 (A1); also elsewhere on the board
/A2: U8.8 (A2); also elsewhere on the board
/A3: U8.7 (A3); also elsewhere on the board
/A4: U8.6 (A4); also elsewhere on the board
/A5: U8.5 (A5); also elsewhere on the board
/A6: U8.4 (A6); also elsewhere on the board
/A7: U8.3 (A7); also elsewhere on the board
/A8: U8.25 (A8); also elsewhere on the board
/A9: U8.24 (A9); also elsewhere on the board
/A10: U8.21 (A10); also elsewhere on the board
/A11: U8.23 (A11); also elsewhere on the board
/A12: U8.2 (A12); also elsewhere on the board
/A13: U8.26 (A13); also elsewhere on the board
/A14: U8.1 (A14); also elsewhere on the board
/D0: U8.11 (D0); also elsewhere on the board
/D1: U8.12 (D1); also elsewhere on the board
/D2: U8.13 (D2); also elsewhere on the board
/D3: U8.15 (D3); also elsewhere on the board
/D4: U8.16 (D4); also elsewhere on the board
/D5: U8.17 (D5); also elsewhere on the board
/D6: U8.18 (D6); also elsewhere on the board
/D7: U8.19 (D7); also elsewhere on the board
/MEM_DECODER/ROM_CS: U8.20 (~CS); also elsewhere on the board
/RD: U8.22 (~OE); also elsewhere on the board
GND: C11.2, U8.14 (GND); also elsewhere on the board
VCC: C11.1, U8.27 (~WE), U8.28 (VCC); also elsewhere on the board

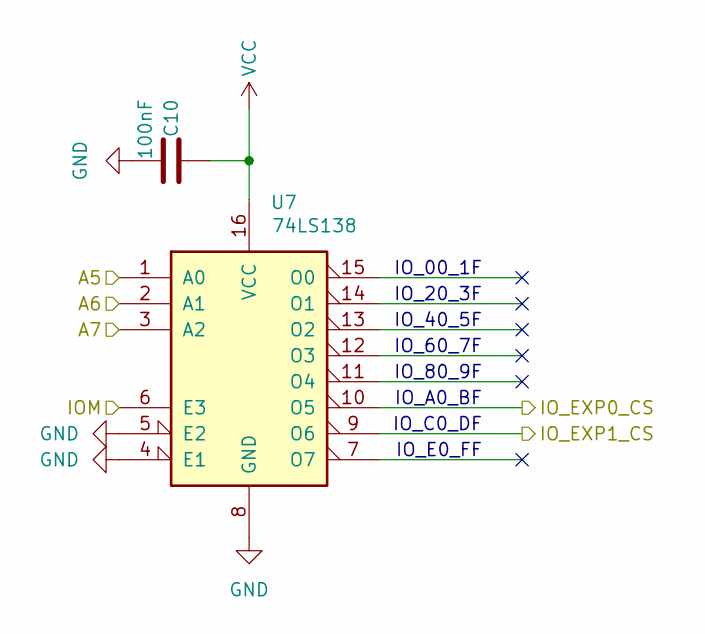
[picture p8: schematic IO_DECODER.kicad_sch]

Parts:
C10: 100nF; C_Disc_D5.0mm_W2.5mm_P5.00mm
U7: 74LS138; DIP-16_W7.62mm_Socket

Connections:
/A5: U7.1 (A0); also elsewhere on the board
/A6: U7.2 (A1); also elsewhere on the board
/A7: U7.3 (A2); also elsewhere on the board
/EXPANSION_CONNECTOR/IO_EXP0_CS: U7.10 (O5); also elsewhere on the board
/EXPANSION_CONNECTOR/IO_EXP1_CS: U7.9 (O6); also elsewhere on the board
/IOM: U7.6 (E3); also elsewhere on the board
GND: C10.2, U7.4 (E1), U7.5 (E2), U7.8 (GND); also elsewhere on the board
VCC: C10.1, U7.16 (VCC); also elsewhere on the board

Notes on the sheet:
IO_A0_BF
IO_20_3F
IO_60_7F
IO_C0_DF
IO_00_1F
IO_E0_FF
IO_40_5F
IO_80_9F

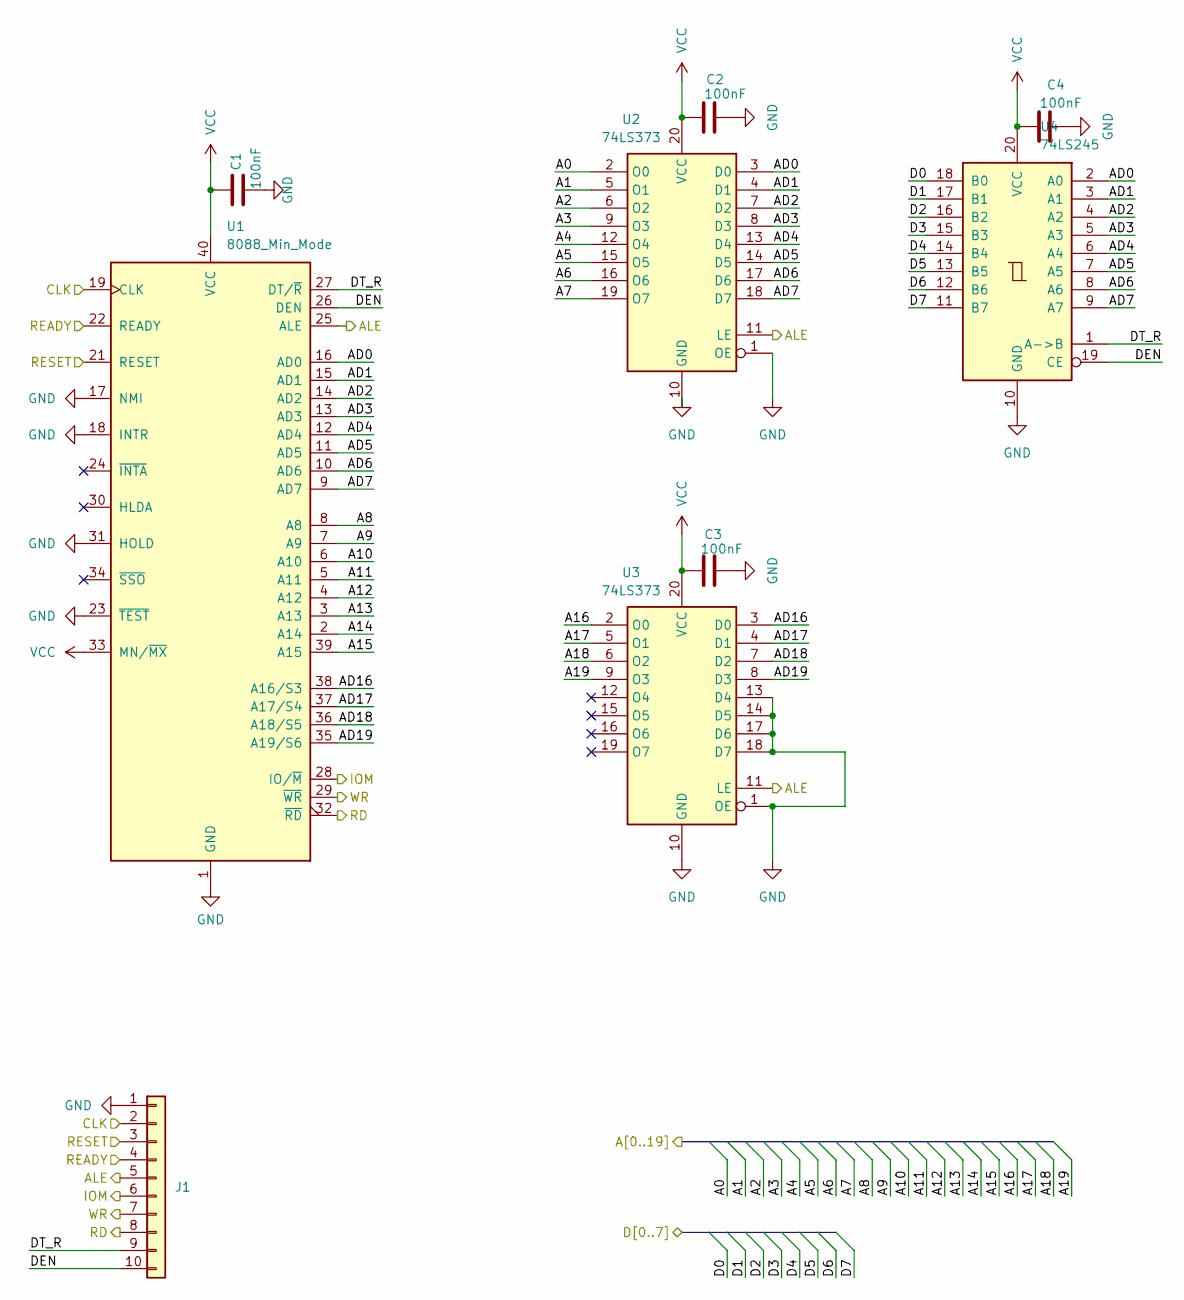
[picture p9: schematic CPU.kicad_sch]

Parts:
C1, C2, C3, C4: 100nF; C_Disc_D5.0mm_W2.5mm_P5.00mm
J1: Conn_01x10; PinHeader_1x10_P2.54mm_Vertical
U1: 8088_Min_Mode; DIP-40_W15.24mm_Socket
U2, U3: 74LS373; DIP-20_W7.62mm_Socket
U4: 74LS245; DIP-20_W7.62mm_Socket

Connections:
/A0: U2.2 (O0); also elsewhere on the board
/A1: U2.5 (O1); also elsewhere on the board
/A2: U2.6 (O2); also elsewhere on the board
/A3: U2.9 (O3); also elsewhere on the board
/A4: U2.12 (O4); also elsewhere on the board
/A5: U2.15 (O5); also elsewhere on the board
/A6: U2.16 (O6); also elsewhere on the board
/A7: U2.19 (O7); also elsewhere on the board
/A8: U1.8 (A8); also elsewhere on the board
/A9: U1.7 (A9); also elsewhere on the board
/A10: U1.6 (A10); also elsewhere on the board
/A11: U1.5 (A11); also elsewhere on the board
/A12: U1.4 (A12); also elsewhere on the board
/A13: U1.3 (A13); also elsewhere on the board
/A14: U1.2 (A14); also elsewhere on the board
/A15: U1.39 (A15); also elsewhere on the board
/A16: U3.2 (O0); also elsewhere on the board
/A17: U3.5 (O1); also elsewhere on the board
/A18: U3.6 (O2); also elsewhere on the board
/A19: U3.9 (O3); also elsewhere on the board
/ALE: J1.5, U1.25 (ALE), U2.11 (LE), U3.11 (LE); also elsewhere on the board
/CLK: J1.2, U1.19 (CLK); also elsewhere on the board
/CPU/AD0: U1.16 (AD0), U2.3 (D0), U4.2 (A0)
/CPU/AD1: U1.15 (AD1), U2.4 (D1), U4.3 (A1)
/CPU/AD2: U1.14 (AD2), U2.7 (D2), U4.4 (A2)
/CPU/AD3: U1.13 (AD3), U2.8 (D3), U4.5 (A3)
/CPU/AD4: U1.12 (AD4), U2.13 (D4), U4.6 (A4)
/CPU/AD5: U1.11 (AD5), U2.14 (D5), U4.7 (A5)
/CPU/AD6: U1.10 (AD6), U2.17 (D6), U4.8 (A6)
/CPU/AD7: U1.9 (AD7), U2.18 (D7), U4.9 (A7)
/CPU/AD16: U1.38 (A16/S3), U3.3 (D0)
/CPU/AD17: U1.37 (A17/S4), U3.4 (D1)
/CPU/AD18: U1.36 (A18/S5), U3.7 (D2)
/CPU/AD19: U1.35 (A19/S6), U3.8 (D3)
/CPU/DEN: J1.10, U1.26 (DEN), U4.19 (CE)
/CPU/DT_R: J1.9, U1.27 (DT/~R), U4.1 (A->B)
/D0: U4.18 (B0); also elsewhere on the board
/D1: U4.17 (B1); also elsewhere on the board
/D2: U4.16 (B2); also elsewhere on the board
/D3: U4.15 (B3); also elsewhere on the board
/D4: U4.14 (B4); also elsewhere on the board
/D5: U4.13 (B5); also elsewhere on the board
/D6: U4.12 (B6); also elsewhere on the board
/D7: U4.11 (B7); also elsewhere on the board
/IOM: J1.6, U1.28 (IO/~M); also elsewhere on the board
/RD: J1.8, U1.32 (~RD); also elsewhere on the board
/READY: J1.4, U1.22 (READY); also elsewhere on the board
/RESET: J1.3, U1.21 (RESET); also elsewhere on the board
/WR: J1.7, U1.29 (~WR); also elsewhere on the board
GND: C1.2, C2.2, C3.2, C4.2, J1.1, U1.1 (GND), U1.17 (NMI), U1.18 (INTR), U1.20 (GND), U1.23 (~TEST), U1.31 (HOLD), U2.1 (OE), U2.10 (GND), U3.1 (OE), U3.10 (GND), U3.13 (D4), U3.14 (D5), U3.17 (D6), U3.18 (D7), U4.10 (GND); also elsewhere on the board
VCC: C1.1, C2.1, C3.1, C4.1, U1.33 (MN/~MX), U1.40 (VCC), U2.20 (VCC), U3.20 (VCC), U4.20 (VCC); also elsewhere on the board

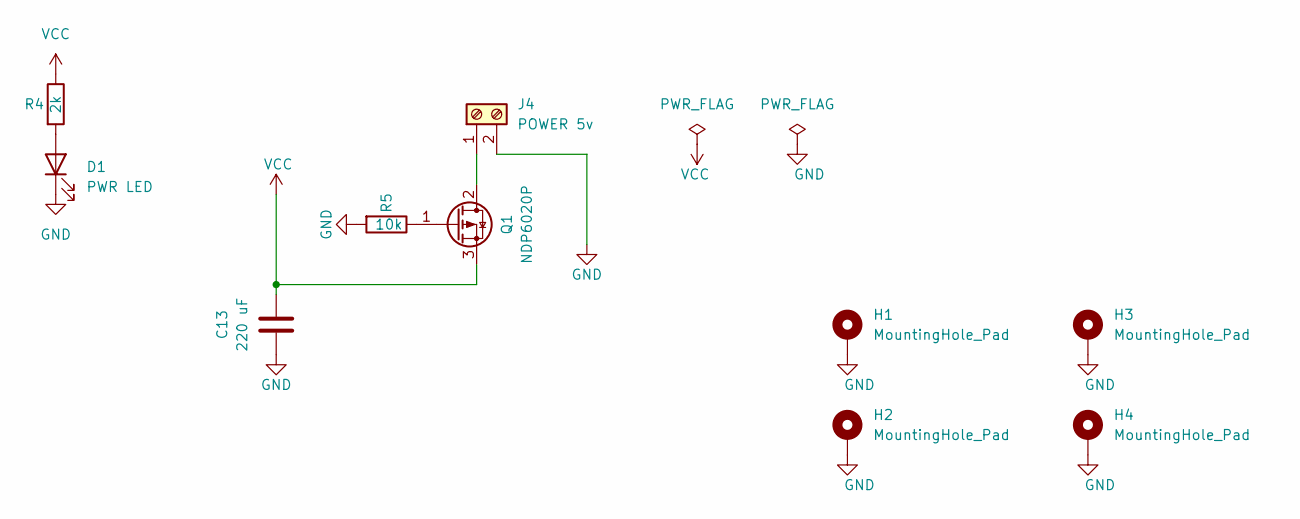
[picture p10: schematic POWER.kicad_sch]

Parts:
C13: 220 uF; CP_Radial_D5.0mm_P2.00mm
D1: PWR LED; LED_D3.0mm
H1, H2, H3, H4: MountingHole_Pad; MountingHole_3.2mm_M3_Pad
J4: POWER 5v; TerminalBlock_Phoenix_MKDS-1,5-2-5.08_1x02_P5.08mm_Horizont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
Q1: NDP6020P; TO-220-3_Horizontal_TabDown
R4: 2k; R_Axial_DIN0207_L6.3mm_D2.5mm_P7.62mm_Horizontal
R5: 10k; R_Axial_DIN0207_L6.3mm_D2.5mm_P7.62mm_Horizontal

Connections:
GND: C13.2, D1.1 (K), H1.1 (1_1), H2.1 (1_1), H3.1 (1_1), H4.1 (1_1), J4.2, R5.2; also elsewhere on the board
unnamed: D1.2 (A), R4.2
unnamed: J4.1, Q1.2 (D)
unnamed: Q1.1 (G), R5.1
VCC: C13.1, Q1.3 (S), R4.1; also elsewhere on the board

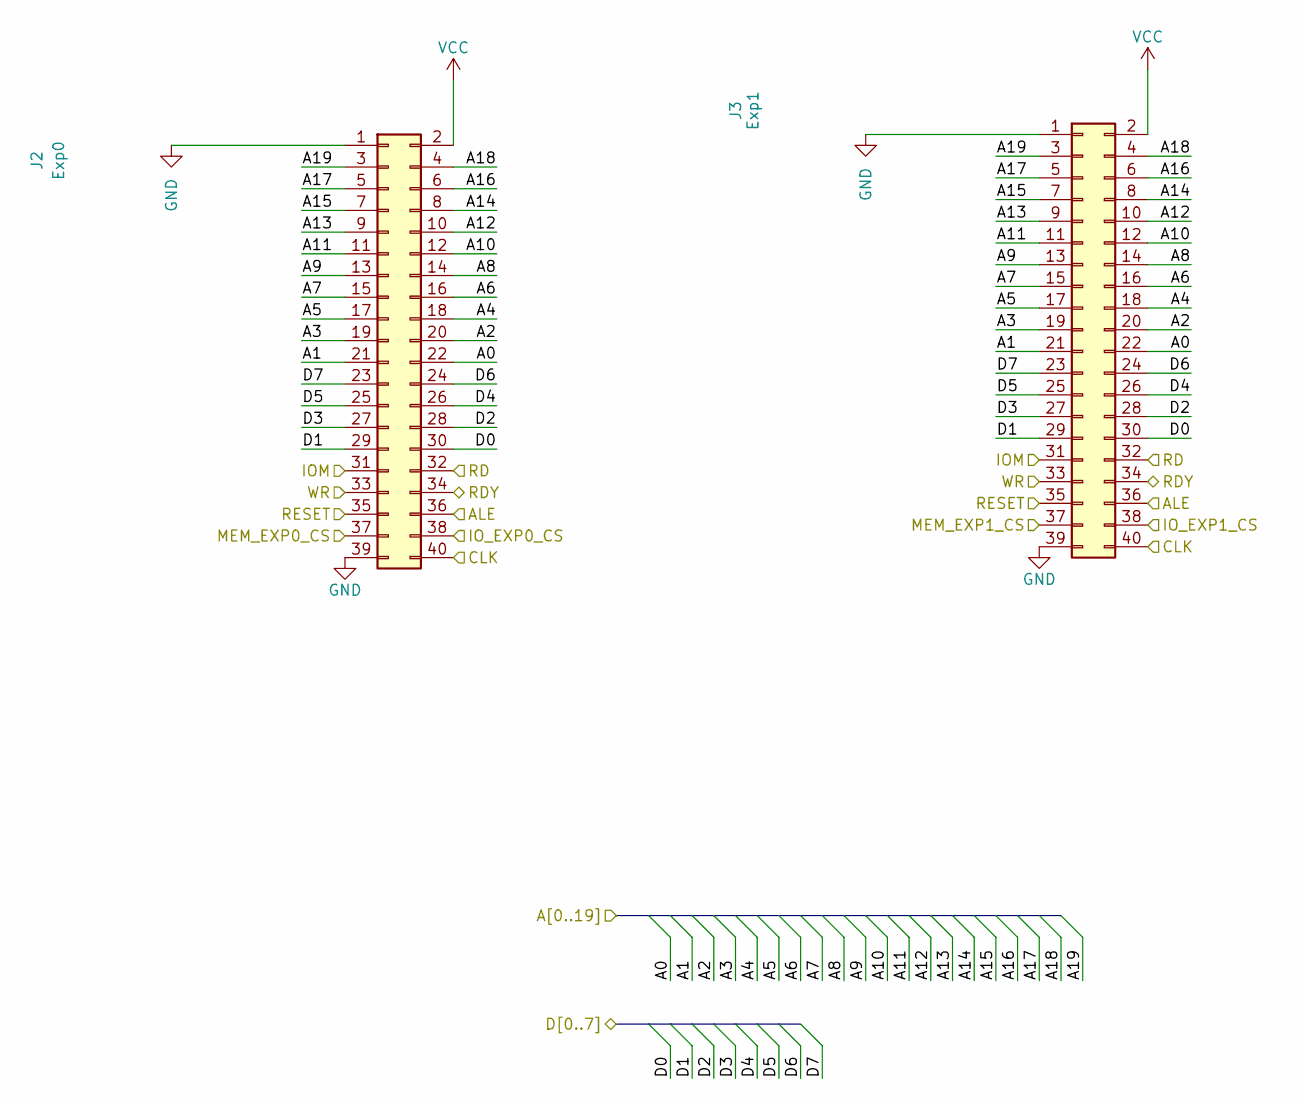
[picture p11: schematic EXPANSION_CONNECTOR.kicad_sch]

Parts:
J2: Exp0; IDC-Header_2x20_P2.54mm_Vertical
J3: Exp1; IDC-Header_2x20_P2.54mm_Vertical

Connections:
/A0: J2.22, J3.22; also elsewhere on the board
/A1: J2.21, J3.21; also elsewhere on the board
/A2: J2.20, J3.20; also elsewhere on the board
/A3: J2.19, J3.19; also elsewhere on the board
/A4: J2.18, J3.18; also elsewhere on the board
/A5: J2.17, J3.17; also elsewhere on the board
/A6: J2.16, J3.16; also elsewhere on the board
/A7: J2.15, J3.15; also elsewhere on the board
/A8: J2.14, J3.14; also elsewhere on the board
/A9: J2.13, J3.13; also elsewhere on the board
/A10: J2.12, J3.12; also elsewhere on the board
/A11: J2.11, J3.11; also elsewhere on the board
/A12: J2.10, J3.10; also elsewhere on the board
/A13: J2.9, J3.9; also elsewhere on the board
/A14: J2.8, J3.8; also elsewhere on the board
/A15: J2.7, J3.7; also elsewhere on the board
/A16: J2.6, J3.6; also elsewhere on the board
/A17: J2.5, J3.5; also elsewhere on the board
/A18: J2.4, J3.4; also elsewhere on the board
/A19: J2.3, J3.3; also elsewhere on the board
/ALE: J2.36, J3.36; also elsewhere on the board
/CLK: J2.40, J3.40; also elsewhere on the board
/D0: J2.30, J3.30; also elsewhere on the board
/D1: J2.29, J3.29; also elsewhere on the board
/D2: J2.28, J3.28; also elsewhere on the board
/D3: J2.27, J3.27; also elsewhere on the board
/D4: J2.26, J3.26; also elsewhere on the board
/D5: J2.25, J3.25; also elsewhere on the board
/D6: J2.24, J3.24; also elsewhere on the board
/D7: J2.23, J3.23; also elsewhere on the board
/EXPANSION_CONNECTOR/IO_EXP0_CS: J2.38; also elsewhere on the board
/EXPANSION_CONNECTOR/IO_EXP1_CS: J3.38; also elsewhere on the board
/EXPANSION_CONNECTOR/MEM_EXP0_CS: J2.37; also elsewhere on the board
/EXPANSION_CONNECTOR/MEM_EXP1_CS: J3.37; also elsewhere on the board
/IOM: J2.31, J3.31; also elsewhere on the board
/RD: J2.32, J3.32; also elsewhere on the board
/RDY: J2.34, J3.34; also elsewhere on the board
/RESET: J2.35, J3.35; also elsewhere on the board
/WR: J2.33, J3.33; also elsewhere on the board
GND: J2.1, J2.39, J3.1, J3.39; also elsewhere on the board
VCC: J2.2, J3.2; also elsewhere on the board

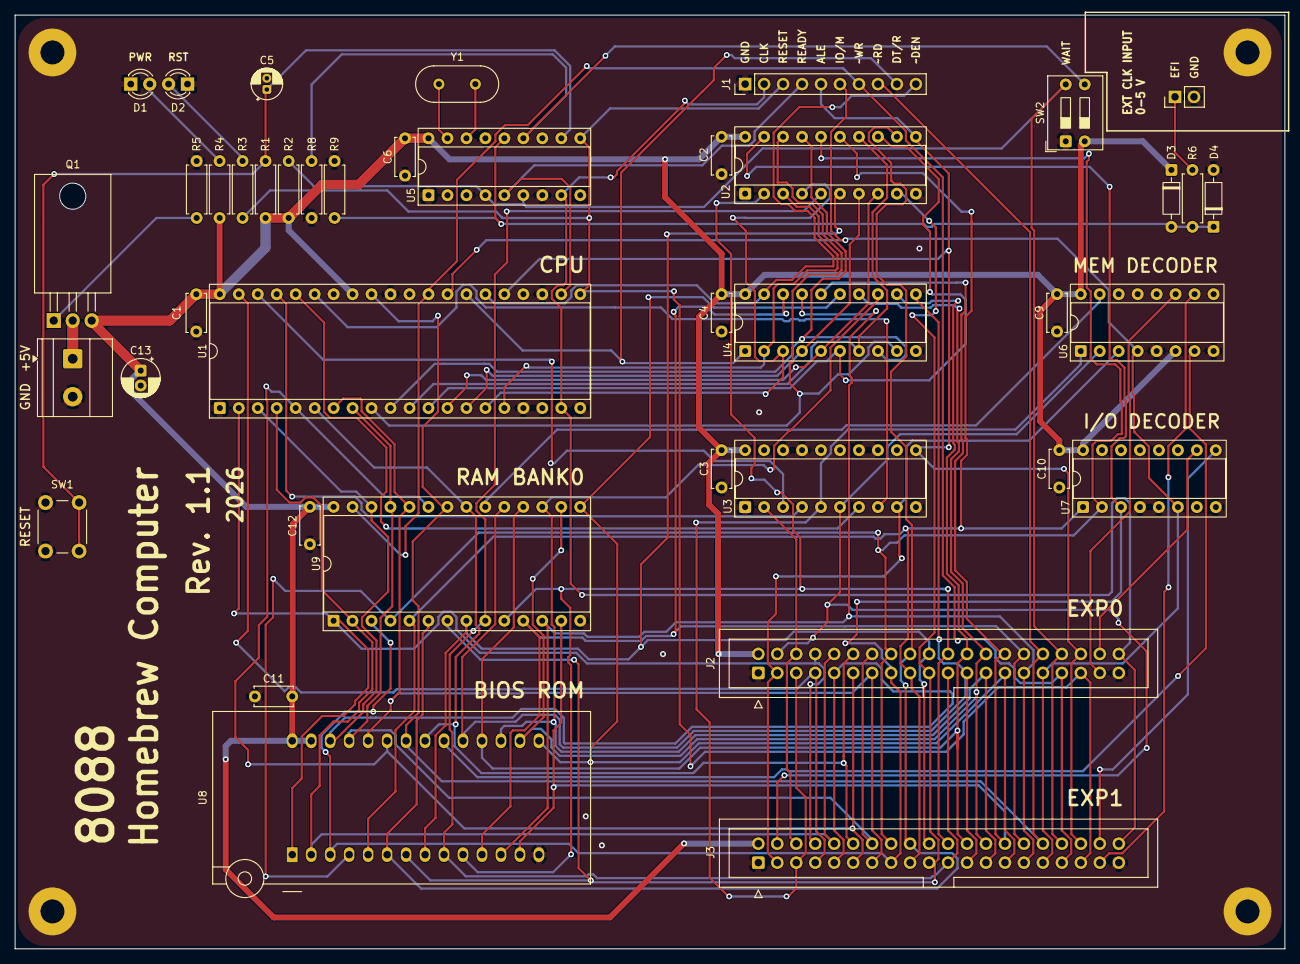
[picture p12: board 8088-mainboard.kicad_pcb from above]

Board: 2 copper layers, 170.0 x 125.0 mm, 45 parts (0 on the bottom side), 68 nets.

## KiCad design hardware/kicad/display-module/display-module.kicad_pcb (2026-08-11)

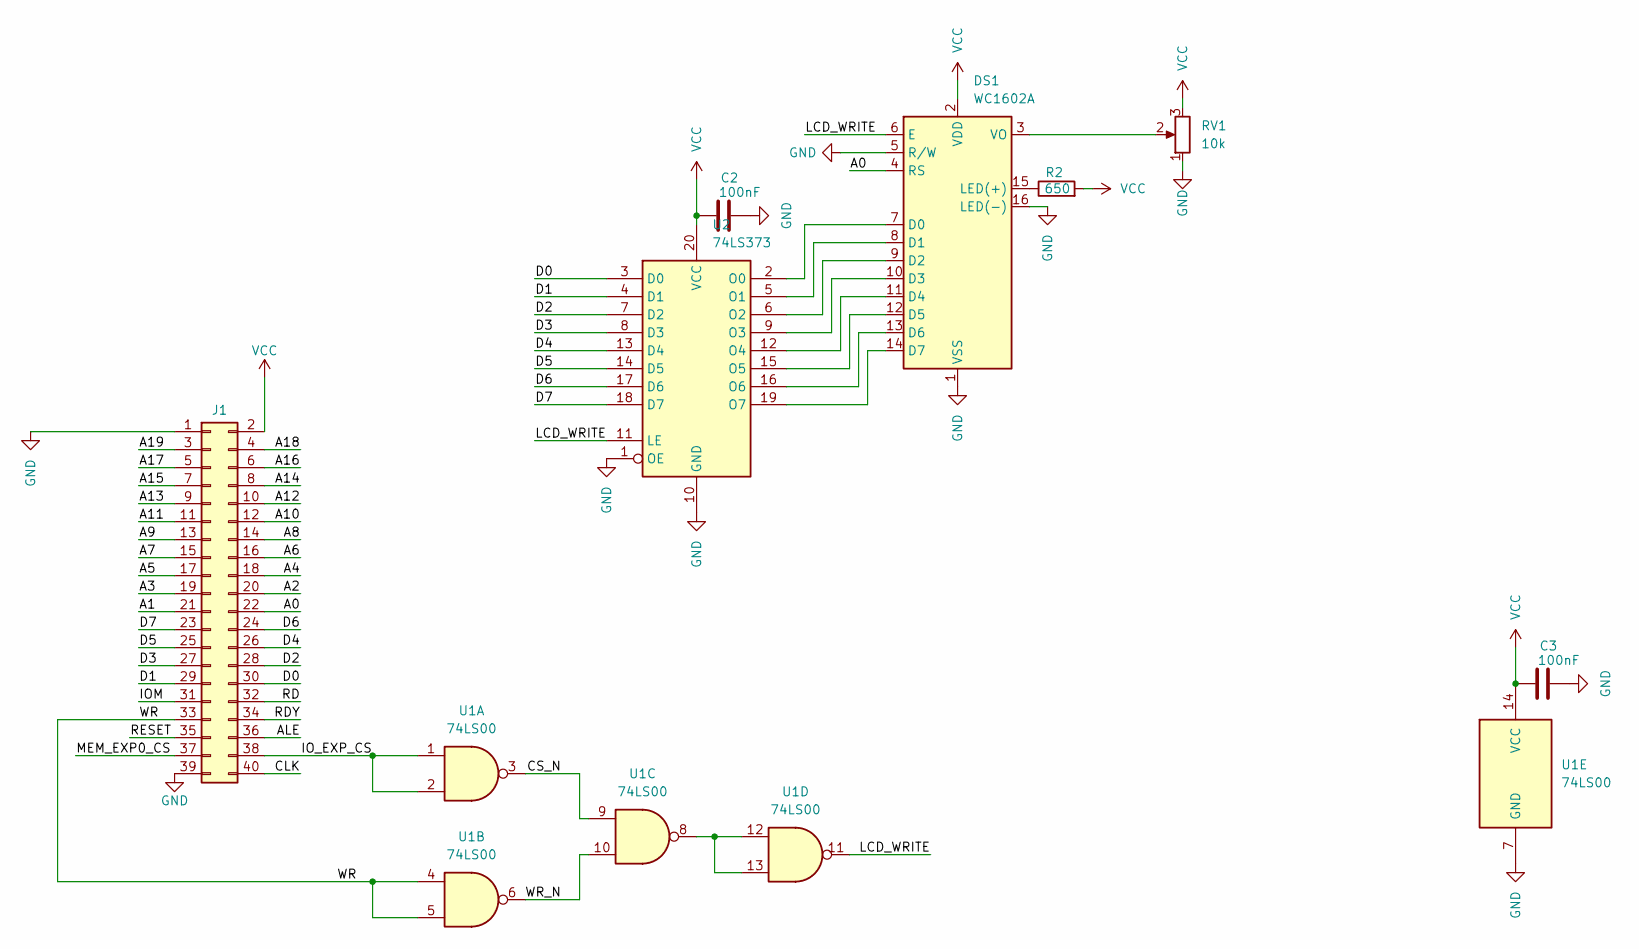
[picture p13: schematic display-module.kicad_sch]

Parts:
C2, C3: 100nF; C_Disc_D5.0mm_W2.5mm_P5.00mm
DS1: WC1602A; PinSocket_1x16_P2.54mm_Vertical
J1: Exp0; PinSocket_2x20_P2.54mm_Vertical
R2: 650; R_Axial_DIN0207_L6.3mm_D2.5mm_P7.62mm_Horizontal
RV1: 10k; Potentiometer_Runtron_RM-065_Vertical
U1: 74LS00; DIP-14_W7.62mm_Socket
U2: 74LS373; DIP-20_W7.62mm_Socket

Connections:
/A0: DS1.4 (RS), J1.22
/A1: J1.21
/A2: J1.20
/A3: J1.19
/A4: J1.18
/A5: J1.17
/A6: J1.16
/A7: J1.15
/A8: J1.14
/A9: J1.13
/A10: J1.12
/A11: J1.11
/A12: J1.10
/A13: J1.9
/A14: J1.8
/A15: J1.7
/A16: J1.6
/A17: J1.5
/A18: J1.4
/A19: J1.3
/ALE: J1.36
/CLK: J1.40
/CS_N: U1.3, U1.9
/D0: J1.30, U2.3 (D0)
/D1: J1.29, U2.4 (D1)
/D2: J1.28, U2.7 (D2)
/D3: J1.27, U2.8 (D3)
/D4: J1.26, U2.13 (D4)
/D5: J1.25, U2.14 (D5)
/D6: J1.24, U2.17 (D6)
/D7: J1.23, U2.18 (D7)
/IOM: J1.31
/IO_EXP_CS: J1.38, U1.1, U1.2
/LCD_WRITE: DS1.6 (E), U1.11, U2.11 (LE)
/MEM_EXP0_CS: J1.37
/RD: J1.32
/RDY: J1.34
/RESET: J1.35
/WR: J1.33, U1.4, U1.5
/WR_N: U1.6, U1.10
GND: C2.2, C3.2, DS1.1 (VSS), DS1.5 (R/W), DS1.16 (LED(-)), J1.1, J1.39, RV1.1, U1.7 (GND), U2.1 (OE), U2.10 (GND)
unnamed: DS1.7 (D0), U2.2 (O0)
unnamed: DS1.8 (D1), U2.5 (O1)
unnamed: DS1.9 (D2), U2.6 (O2)
unnamed: DS1.10 (D3), U2.9 (O3)
unnamed: DS1.11 (D4), U2.12 (O4)
unnamed: DS1.12 (D5), U2.15 (O5)
unnamed: DS1.13 (D6), U2.16 (O6)
unnamed: DS1.14 (D7), U2.19 (O7)
unnamed: DS1.15 (LED(+)), R2.1
unnamed: DS1.3 (VO), RV1.2
unnamed: U1.8, U1.12, U1.13
VCC: C2.1, C3.1, DS1.2 (VDD), J1.2, R2.2, RV1.3, U1.14 (VCC), U2.20 (VCC)

Board: 2 copper layers, 8 parts (2 on the bottom side), 27 nets, no tracks yet.

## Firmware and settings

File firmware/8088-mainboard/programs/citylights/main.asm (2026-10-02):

BITS 16
CPU 8086
ORG 0

; A stationary city alternates between night and day. Clouds drift across
; the sky; a two-column wipe replaces each scene from the right.

%include "bios_api.inc"

SCREEN_CELLS equ BIOS_LCD_COLUMNS * BIOS_LCD_ROWS
; Rev1 has no timer. One polling delay is roughly 1/8 second at 4.77 MHz.
TICKS_PER_SECOND equ 8
INTRO_TICKS      equ 2 * TICKS_PER_SECOND
SCENE_TICKS      equ 5 * TICKS_PER_SECOND
HINT_ON_TICKS    equ 3 * TICKS_PER_SECOND
HINT_OFF_TICKS   equ 10 * TICKS_PER_SECOND
WIPE_COLUMNS     equ 2
MOON_GLYPH   equ 0
SUN_GLYPH    equ 1
STAR_GLYPH   equ 2
CLOUD_GLYPH  equ 3
ROOF_GLYPH   equ 4
DARK_WALL    equ 0FFh            ; Built-in solid block, freeing a custom glyph.
LOW_BUILDING equ 5
LIT_WALL     equ 6
WALKER_GLYPH equ 7

start:
    cli
    cld
    mov ax, cs
    mov ds, ax

    bios_lcd_clear
    bios_lcd_glyph MOON_GLYPH, moon_glyph
    bios_lcd_glyph SUN_GLYPH, sun_glyph
    bios_lcd_glyph STAR_GLYPH, star_glyph
    bios_lcd_glyph CLOUD_GLYPH, cloud_glyph_a
    bios_lcd_glyph ROOF_GLYPH, roof_glyph
    bios_lcd_glyph LOW_BUILDING, low_building_glyph
    bios_lcd_glyph LIT_WALL, lit_wall_glyph
    bios_lcd_glyph WALKER_GLYPH, walker_glyph_a

    mov di, old_frame
    call fill_spaces
    call draw_intro
    call present_frame
    mov byte [intro_ticks_left], INTRO_TICKS
.intro:
    call delay_tick
    jc .done
    dec byte [intro_ticks_left]
    jnz .intro

    mov byte [current_scene], 0     ; 0=night, 1=day
    mov byte [scene_tick], 0
    mov byte [cloud_variant], 0
    mov byte [cloud_shift], 0
    mov byte [hold_ticks_left], SCENE_TICKS
    mov byte [wipe_boundary], BIOS_LCD_COLUMNS
    mov byte [hint_ticks_left], HINT_ON_TICKS
    mov byte [hint_visible], 1
.frame:
    call build_night
    call build_day
    call compose_frame
    call present_frame
    call delay_tick
    jc .done
    inc byte [scene_tick]
    call update_cloud_shape
    call update_walker_shape
    call update_hint
    call update_scene
    jmp .frame

.done:
    retf

draw_intro:
    mov di, next_frame
    call copy_city
    mov si, intro_title
    mov di, next_frame + BIOS_LCD_COLUMNS + 4
    mov cx, 11
.letter:
    mov al, [si]
    mov [di], al
    inc si
    inc di
    loop .letter
    ret

; DI=destination. Copy the fixed skyline to a scene buffer.
copy_city:
    mov si, city_frame
    mov cx, SCREEN_CELLS
.cell:
    mov al, [si]
    mov [di], al
    inc si
    inc di
    loop .cell
    ret

build_night:
    mov di, night_frame
    call copy_city
    mov byte [night_frame + 17], MOON_GLYPH

    ; Keep four stars in place: two shine while the others remain dim dots.
    mov byte [night_frame + 3], '.'
    mov byte [night_frame + 11], '.'
    mov byte [night_frame + BIOS_LCD_COLUMNS + 6], '.'
    mov byte [night_frame + BIOS_LCD_COLUMNS + 15], '.'
    ; Switch the bright pair every two polling ticks.
    mov al, [scene_tick]
    shr al, 1
    and al, 3
    xor bx, bx
    mov bl, al
    mov dl, [star_one_cells + bx]
    xor dh, dh
    mov si, dx
    mov byte [night_frame + si], STAR_GLYPH
    mov dl, [star_two_cells + bx]
    mov si, dx
    mov byte [night_frame + si], STAR_GLYPH

    mov byte [night_frame + 3 * BIOS_LCD_COLUMNS + 1], LIT_WALL
    mov byte [night_frame + 3 * BIOS_LCD_COLUMNS + 8], LIT_WALL
    ; One more window changes every two seconds.
    mov al, [scene_tick]
    mov cl, 4
    shr al, cl
    and al, 7
    mov bl, al
    mov dl, [window_columns + bx]
    xor dh, dh
    mov si, dx
    mov byte [night_frame + 3 * BIOS_LCD_COLUMNS + si], LIT_WALL
    ret

build_day:
    mov di, day_frame
    call copy_city
    mov dh, 0
    mov dl, 4
    call draw_cloud
    mov dh, 1
    mov dl, 8
    call draw_cloud
    mov dl, 14
    call draw_cloud
    ; Keep the sun fixed even when a cloud crosses its cell.
    mov byte [day_frame + 17], SUN_GLYPH
    ret

; DH=row, DL=starting column. Wrap the drifting cloud at the left edge.
draw_cloud:
    sub dl, [cloud_shift]
    jnc .column
    add dl, BIOS_LCD_COLUMNS
.column:
    xor bx, bx
    mov bl, dl
    cmp dh, 0
    je .store
    add bx, BIOS_LCD_COLUMNS
.store:
    mov byte [day_frame + bx], CLOUD_GLYPH
    ret

compose_frame:
    ; Columns to the right of the boundary belong to the incoming scene.
    mov si, night_frame
    mov bx, day_frame
    cmp byte [current_scene], 0
    je .pointers
    xchg si, bx
.pointers:
    mov di, next_frame
    xor dx, dx                   ; DL=column within each LCD row.
    mov cx, SCREEN_CELLS
.cell:
    cmp dl, [wipe_boundary]
    jb .old_scene
    mov al, [bx]
    jmp short .write
.old_scene:
    mov al, [si]
.write:
    mov [di], al
    inc si
    inc bx
    inc di
    inc dl
    cmp dl, BIOS_LCD_COLUMNS
    jb .next
    xor dl, dl
.next:
    loop .cell

    call draw_walker
    cmp byte [hint_visible], 0
    je .done
    mov si, hint_text
    mov di, next_frame + 3 * BIOS_LCD_COLUMNS + 12
    mov cx, 8
.hint:
    mov al, [si]
    mov [di], al
    inc si
    inc di
    loop .hint
.done:
    ret

; One pedestrian paces between the two left-hand buildings.
draw_walker:
    mov al, [scene_tick]
    mov cl, 2
    shr al, cl
    and al, 1
    add al, 4                    ; Alternate between columns 4 and 5.
    xor ah, ah
    mov si, ax
    mov byte [next_frame + 3 * BIOS_LCD_COLUMNS + si], WALKER_GLYPH
    ret

update_scene:
    cmp byte [wipe_boundary], BIOS_LCD_COLUMNS
    jne .wiping
    dec byte [hold_ticks_left]
    jnz .done
    mov byte [wipe_boundary], BIOS_LCD_COLUMNS - WIPE_COLUMNS
    ret
.wiping:
    cmp byte [wipe_boundary], 0
    je .finish
    sub byte [wipe_boundary], WIPE_COLUMNS
    ret
.finish:
    xor byte [current_scene], 1
    mov byte [wipe_boundary], BIOS_LCD_COLUMNS
    mov byte [hold_ticks_left], SCENE_TICKS
.done:
    ret

update_hint:
    dec byte [hint_ticks_left]
    jnz .done
    xor byte [hint_visible], 1
    cmp byte [hint_visible], 0
    je .hide
    mov byte [hint_ticks_left], HINT_ON_TICKS
    ret
.hide:
    mov byte [hint_ticks_left], HINT_OFF_TICKS
.done:
    ret

update_cloud_shape:
    mov al, [scene_tick]
    and al, TICKS_PER_SECOND - 1
    jnz .done
    inc byte [cloud_shift]
    cmp byte [cloud_shift], BIOS_LCD_COLUMNS
    jb .shifted
    mov byte [cloud_shift], 0
.shifted:
    xor byte [cloud_variant], 1
    cmp byte [cloud_variant], 0
    je .first
    bios_lcd_glyph CLOUD_GLYPH, cloud_glyph_b
    ret
.first:
    bios_lcd_glyph CLOUD_GLYPH, cloud_glyph_a
.done:
    ret

update_walker_shape:
    mov al, [scene_tick]
    and al, 3
    jnz .done
    test byte [scene_tick], 4
    jz .first
    bios_lcd_glyph WALKER_GLYPH, walker_glyph_b
    ret
.first:
    bios_lcd_glyph WALKER_GLYPH, walker_glyph_a
.done:
    ret

; DI=destination. Preserve the caller's other registers except AX/CX/DI.
fill_spaces:
    mov cx, SCREEN_CELLS
    mov al, ' '
.cell:
    mov [di], al
    inc di
    loop .cell
    ret

; Write only LCD cells that changed. INT 60h/AH=04h preserves SI, DI and DX.
present_frame:
    mov si, next_frame
    mov di, old_frame
    xor dx, dx
.cell:
    mov al, [si]
    cmp al, [di]
    je .next
    mov [di], al
    mov ah, 04h
    int BIOS_INT_BOARD
.next:
    inc si
    inc di
    inc dl
    cmp dl, BIOS_LCD_COLUMNS
    jb .cell
    xor dl, dl
    inc dh
    cmp dh, BIOS_LCD_ROWS
    jb .cell
    ret

delay_tick:
    ; Poll between short delay slices: rev1 has no keyboard IRQ.
    mov dx, 128
.chunk:
    mov cx, 256
.wait:
    loop .wait
    bios_key_peek
    jz .next
    bios_key_read
    cmp al, 1Bh
    je .cancel
.next:
    dec dx
    jnz .chunk
    clc
    ret
.cancel:
    stc
    ret

intro_ticks_left: db 0
current_scene:    db 0
scene_tick:       db 0
cloud_variant:    db 0
cloud_shift:      db 0
hold_ticks_left:  db 0
wipe_boundary:    db 0
hint_ticks_left:  db 0
hint_visible:     db 0
intro_title: db 'CITY LIGHTS'
hint_text:   db 'ESC:BACK'
star_one_cells: db 3, 11, 3, 11
star_two_cells: db 26, 35, 35, 26
window_columns: db 1, 2, 7, 8, 9, 14, 15, 16

; The upper two rows are sky; the lower two form a fixed skyline.
city_frame:
    times BIOS_LCD_COLUMNS db ' '
    times BIOS_LCD_COLUMNS db ' '
    db ' ', ROOF_GLYPH, ROOF_GLYPH, ' ', ' ', ' ', ' '
    db ROOF_GLYPH, ROOF_GLYPH, ROOF_GLYPH, ' ', ' ', ' ', ' '
    db ROOF_GLYPH, ROOF_GLYPH, ROOF_GLYPH, ' ', ' ', ' '
    db ' ', DARK_WALL, DARK_WALL, ' ', ' ', ' ', ' '
    db DARK_WALL, DARK_WALL, DARK_WALL, ' ', LOW_BUILDING, LOW_BUILDING, ' '
    db DARK_WALL, DARK_WALL, DARK_WALL, ' ', LOW_BUILDING, LOW_BUILDING

old_frame:   times SCREEN_CELLS db ' '
next_frame:  times SCREEN_CELLS db ' '
night_frame: times SCREEN_CELLS db ' '
day_frame:   times SCREEN_CELLS db ' '

; Each glyph is one 5x8 LCD cell.
moon_glyph:
    db 00110b, 01100b, 11000b, 11000b, 11000b, 01100b, 00110b, 00000b
sun_glyph:
    db 00100b, 10101b, 01110b, 11111b, 01110b, 10101b, 00100b, 00000b
star_glyph:
    db 00100b, 00100b, 10101b, 01110b, 10101b, 00100b, 00100b, 00000b
cloud_glyph_a:
    db 00000b, 00110b, 01111b, 11111b, 11111b, 01110b, 00000b, 00000b
cloud_glyph_b:
    db 00000b, 01100b, 11110b, 11111b, 11111b, 00111b, 00000b, 00000b
roof_glyph:
    db 00000b, 00000b, 11111b, 11111b, 10101b, 11111b, 10101b, 11111b
low_building_glyph:
    db 00000b, 00000b, 00000b, 11111b, 11111b, 11111b, 11111b, 11111b
lit_wall_glyph:
    db 11111b, 11111b, 10001b, 11111b, 11111b, 10001b, 11111b, 11111b
walker_glyph_a:
    db 00000b, 00100b, 00100b, 01110b, 00100b, 01010b, 10001b, 00000b
walker_glyph_b:
    db 00000b, 00100b, 00100b, 01110b, 00100b, 01010b, 01010b, 00000b

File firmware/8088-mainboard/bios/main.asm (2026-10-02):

BITS 16
CPU 8086
ORG 0

; Supplied by Make/CI, never a release number hardcoded in the ROM sources.
%ifndef BIOS_VERSION
    %error "BIOS_VERSION is required; build with make"
%endif
%strlen BIOS_VERSION_LENGTH BIOS_VERSION
%if BIOS_VERSION_LENGTH < 1 || BIOS_VERSION_LENGTH > 9
    %error "BIOS_VERSION must be 1..9 characters to fit the LCD Info row"
%endif
%assign BIOS_VERSION_INDEX 1
%rep BIOS_VERSION_LENGTH
    %substr BIOS_VERSION_CHAR BIOS_VERSION BIOS_VERSION_INDEX, 1
    %if !((BIOS_VERSION_CHAR >= 'a' && BIOS_VERSION_CHAR <= 'z') || (BIOS_VERSION_CHAR >= 'A' && BIOS_VERSION_CHAR <= 'Z') || (BIOS_VERSION_CHAR >= '0' && BIOS_VERSION_CHAR <= '9') || BIOS_VERSION_CHAR = '.' || BIOS_VERSION_CHAR = '-' || BIOS_VERSION_CHAR = '_')
        %error "BIOS_VERSION may contain only ASCII letters, digits, dots, hyphens or underscores"
    %endif
    %assign BIOS_VERSION_INDEX BIOS_VERSION_INDEX + 1
%endrep

; The reset vector jumps here at F800:0000. The monitor executes in ROM;
; only its packet buffers, upload state, and user programs occupy SRAM.
jmp start

%include "lcd.inc"
%include "memory.inc"
%include "uart16550.inc"

; Initialize revision-1 hardware and enter the menu without a splash screen.
start:
    cli
    cld
    xor ax, ax
    mov ss, ax
    mov sp, SRAM_STACK_TOP
    mov ax, cs
    mov ds, ax

    call lcd_initialize
    call uart_initialize
    call api_initialize
    jmp monitor_ready

%include "state.inc"
%include "monitor.inc"
%include "uart/framing.inc"
%include "uart/protocol.inc"
%include "keyboard.inc"
%include "uart/keyboard.inc"
%include "programs.inc"
%include "uart/programs.inc"
%include "uart/memory_read.inc"
%include "uart/memory_write.inc"
%include "menu.inc"
%include "boot.inc"
%include "utils/memory_check.inc"
%include "uart/info.inc"
%include "info.inc"
%include "api.inc"
%include "uart/flasher_mode.inc"

; 8088 reset vector at physical FFFF0h = EEPROM offset 7FF0h.
times 7FF0h - ($ - $$) db 0FFh
    jmp ROM_SEGMENT:0000h

; Complete 32 KiB image for the 28C256 EEPROM.
times 8000h - ($ - $$) db 0FFh

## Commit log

2026-07-02 Add 8088 mainboard KiCad project
    [8088-mainboard.kicad_pcb, 8088-mainboard.kicad_sch, CLOCK.kicad_sch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]
2026-07-07 Add PSB board design
    [8088-mainboard.kicad_pcb, 8088-mainboard.kicad_sch, CPU.kicad_sch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]
2026-07-08 Update 8088-mainboard schematics for refined connections and label adjustments
    [8088-mainboard.kicad_pcb, 8088-mainboard.kicad_sch, CLOCK.kicad_sch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]
2026-07-09 Update 8088-mainboard PCB
    [8088-mainboard.kicad_pcb]
2026-07-11 Update 8086-mainboard scheme
    [8088-mainboard.kicad_pcb, 8088-mainboard.kicad_sch, CLOCK.kicad_sch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]
2026-07-12 Update 8088-mainboard schematics
    [8088-mainboard.kicad_pcb, 8088-mainboard.kicad_sch, CPU.kicad_sch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]
2026-07-24 Finalize 8088 mainboard rev1.0 for production
    [8088-mainboard.kicad_pcb, 8088-mainboard.kicad_sch, CLOCK.kicad_sch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]
2026-08-11 Add LCD module and demo BIOS
    [8088-mainboard.kicad_pcb, CLOCK.kicad_sch, display-module.kicad_pcb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]
2026-08-21 Add UART module
    [8088-mainboard.kicad_pcb, 8088-mainboard.kicad_sch, CLOCK.kicad_sch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]
2026-08-21 Finalize 8088 mainboard rev1.1 for production and update README formatting
    [8088-mainboard.kicad_pcb]
2026-10-02 Add new BIOS and boardctl utility
    [uart-module.kicad_pcb]
2026-10-25 Add HOME8088 OS, PC/XT BIOS services, and UART protocol 2.0 (#9)
    Boot a native single-task OS from a FAT12 floppy served over UART and run COM applications with independent stacks.
    Add stack-independent BIOS state, PC/XT timer and disk services, optional RAM/PIC/PIT detection, and diagnostics. Move application loading into the OS and simplify BIOS and boardctl around protocol 2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
2026-10-26 Add MS-DOS 2.0 support (#10)
    * Add MS-DOS 2.0 support
    Boot the original Microsoft MS-DOS 2.00 kernel and COMMAND 2.02 from a FAT12 floppy served over UART through a board-specific OEM I/O layer.
    Add Microsoft DEBUG and Zork I with a console interpreter for the 8088. Pin upstream sources and binaries with SHA-256 verification.
    Support disk writes through BIOS INT 13h, the DOS driver, and boardctl. Make images writable by default with explicit --disk-readonly protection. Lock writable images and sync and verify each sector before acknowledging completion, with safe UART retries.
    Validate file operations, directories, batch execution, persistence after reboot, DEBUG, and Zork save/restore.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
2026-11-01 Replace Reactor with LCD timer (#11)
    - Add a PIT-based countdown timer with pause, resume, and reset controls
    - Keep Citylights animation on the LCD and limit UART to service messages
    - Retry rejected keyboard events in order while servicing disk and output
    - Update the default HOME8088 image, documentation, and regression tests
